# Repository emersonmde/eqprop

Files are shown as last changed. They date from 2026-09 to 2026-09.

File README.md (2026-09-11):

# Analog equilibrium propagation — XOR prototype B.1

A two-hidden-node analog resistive network for learning XOR through equilibrium propagation. The circuit settles physically; a classic 5 V Arduino Nano will measure equilibria and update sixteen programmable resistances. **The PCB is routed and checked; Nano firmware and physical validation are not yet implemented/completed.**

Start every new session with [project state and next steps](docs/project-state.md). It records what exists, what remains, and where to find the design, fabrication, programming and debugging instructions.

## Working files

- [Native KiCad project](cad/eqprop-xor/eqprop-xor.kicad_pro), including its child sheets and local libraries.
- [Design rationale and datasheets](docs/design.md), [component/pin tables](docs/kicad/00-overview.md), [preferred-parts BOM](docs/bom-pcbway.csv).
- [PCBWay fabrication and assembly](docs/fabrication.md).
- [Nano firmware contract](docs/firmware.md), [bench bring-up](docs/bring-up.md), [demo operation](docs/operation.md).
- [Engineering review](docs/ee-review.md), [validation evidence](docs/validation/).

## Simulation and release checks

From the repository root, using Python 3 and a virtual environment:

```sh
python3 -m venv .venv
source .venv/bin/activate
python -m pip install -r sim/requirements.txt
PYTHONPATH=sim python -m pytest sim/tests -q
PYTHONPATH=sim python -m eqprop.xor
python tools/generate_bom.py
python tools/export_manufacturing.py
```

Install ngspice for the SPICE tests; those tests skip when it is absent, so skipped tests do not constitute a complete release check. KiCad 9's `kicad-cli` is required for manufacturing export. The script discovers PATH or the standard macOS install; `--kicad-cli` can specify another executable. Generated fabrication files go in ignored `build/manufacturing/`. Save the exact approved release with the PCBWay order records when an order is placed.

The regression suite checks KCL, gradients, training, quantization, SPICE behavior and BOM consistency. These are retained because later hardware/firmware changes need them. Nominal DC models do not prove stability, noise, component spread or online finite-tap learning.

## Papers and Attribution

This project is a from-scratch implementation of techniques described in the following papers. No code was reused from any existing repository.

**Core algorithm:**
- Scellier & Bengio, ["Equilibrium Propagation: Bridging the Gap Between Energy-Based Models and Backpropagation"](https://arxiv.org/abs/1602.05179) (Frontiers in Computational Neuroscience, 2017) — the equilibrium propagation framework: free-phase settling, nudge-phase perturbation, and gradient extraction from energy differences.

**Analog hardware formulation:**
- Kendall et al., ["Training End-to-End Analog Neural Networks with Equilibrium Propagation"](https://arxiv.org/abs/2006.01981) (2020) — extends EqProp to nonlinear resistive networks. This project uses their conductance-space gradient formula (Theorem 1: `dC/dG = (dV_nudge² - dV_free²) / (2β)`), their proof that antiparallel diode pairs are valid EqProp nonlinear elements (Theorem 2), and their XOR demonstration architecture (Figure 3, Appendix D.2) as a starting point. The complementary-input encoding and digital-weight-update pattern also follow their approach.

**Symmetric nudging:**
- Laborieux et al., ["Scaling Equilibrium Propagation to Deep ConvNets by Drastically Reducing its Computational Cost"](https://arxiv.org/abs/2006.03824) (ICLR 2021) — the symmetric nudge variant (both +β and -β) used in the training loop to cancel gradient estimation bias.

**Referenced in the hardware design upgrade path:**
- Laborieux & Zenke, ["Holomorphic Equilibrium Propagation Computes Exact Gradients Through Finite Size Oscillations"](https://arxiv.org/abs/2209.00530) (NeurIPS 2022) — oscillating nudge + DFT-based gradient extraction for exact gradients without finite-β bias.

## License

Apache 2.0. See [LICENSE](LICENSE).

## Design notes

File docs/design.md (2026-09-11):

# Revision B.1 update

B.1 adds a locally routed learn/stop input on Nano A6 and operating labels; the analog design below remains unchanged. See [usability revision](usability-revision.md).

# EqProp XOR — revision B

Revision B.1 is the current prototype design. The native KiCad hierarchy, PCB and `bom-pcbway.csv` supersede the revision A construction notes retained in Git history. Revision A had functional errors that passing a routing DRC could not detect.

## Signal path

Sixteen MCP4251-104E/SL programmable resistances form a complementary-input, two-hidden-node, differential-output network. TLV9064 buffers generate V_LOW and V_HIGH and separate V_MID returns for the two diode activations and current sources. Two TMUX1133PWR devices select the complementary inputs. Four BAT42W diodes implement the hidden-node nonlinearities. U17 buffers H1, H2, YP and YN before the ADS1115; 100 ohm/1 nF filters isolate its switched-capacitor inputs from the buffers.

## Corrections and component decisions

* U4/U5 select pins are 11=A and 10=B; common analog pins are 14=X1 and 15=X2 (and complementary equivalents). The previous schematic interchanged these groups. TMUX1133 uses the verified compatible pin arrangement with much lower on-resistance than CD4053B. [TI TMUX1133](https://www.ti.com/lit/ds/symlink/tmux1133.pdf)
* U1/U2/U17 use TLV9064IDR and U15 uses TLV9062IDR. CMOS input bias and rail-to-rail operation suit the high-impedance analog network. Input offset, drift and reference errors still require calibration. The 1 uF reference capacitors filter divider inputs; large capacitors no longer directly load buffer outputs. [TI TLV906x](https://www.ti.com/lit/ds/symlink/tlv9064.pdf)
* Each programmable weight has a 2.49 kohm, 1% fixed series resistor. With a 5.5 V maximum rail difference and the resistor at its -1% corner, current is below 2.24 mA even without relying on pot resistance. MCP4251 terminal current is limited to 2.5 mA. The nominal 75 ohm wiper and tied W/B terminals are included in the revised model. Device resistance tolerance means taps must be calibrated if absolute conductance is important. [Microchip DS22060B](https://ww1.microchip.com/downloads/aemDocuments/documents/OTH/ProductDocuments/DataSheets/22060b.pdf)
* ADS1115 inputs now see buffered signals rather than directly loading the learning nodes. Readings still require settling after channel switching and changes to input/weight/DAC settings. [TI ADS1115](https://www.ti.com/lit/ds/symlink/ads1115.pdf)
* Precision dividers, the differential amplifier and pump resistor ratios use 0.1%, 25 ppm/K thin-film resistors. Other resistors use common thick-film parts. Precision MPNs specify lead-free TNPW e3, not the similarly named lead-bearing TNPW series. [Vishay TNPW e3](https://www.vishay.com/docs/28758/tnpw_e3.pdf)

## Balanced nudge sources

Each pump uses Rin=1M from DAC to the positive input, Rpos=1M from positive input to load, Rout=1M from amplifier output to load, Rref=10k from V_MID_PUMP to negative input, and Rfb=20k from output to negative input. All five are 0.1%.

The balance condition is `(Rfb/Rref)*Rin = Rpos + Rout`. Including current through both load-connected resistors gives:

`I_load = 2 uA/V * (V_DAC - V_MID_PUMP)`

The previous 10k/10k/10k/10k/1M arrangement was not balanced and substantially loaded the network in its purported free phase. These are equations for the actual five-resistor topology, not a generic four-resistor current-source formula. [TI AN-1515](https://www.ti.com/lit/an/snoa474a/snoa474a.pdf)

For the balanced circuit, `V_amp = 1.5*(V_DAC + V_load) - 2*V_MID_PUMP`. Firmware must enforce output compliance and the DAC's physical output range. A conservative initial operating region is V_DAC within +/-0.5 V of measured V_MID_PUMP, with node voltages near midrail. Calculate bounds from actual supply and load voltage; do not blindly clamp only to DAC codes. Maintain at least 0.15 V estimated output headroom as a bring-up guard, then characterize the real load-dependent swing.

## Classifier

U1C produces `PRED = V_MID_PUMP + YP_BUF - YN_BUF` using four 100k, 0.1% resistors. U18A compares this against a hysteretic threshold derived from a 4.99k/5.62k divider. U18B inverts its logic to drive the complementary indicator. This gives a nominal midpoint near +0.148 V differential at 5 V supply, appropriate for XOR targets 0 and +0.3 V. A zero-difference comparator was inappropriate for those targets.

The 10k input and 2M feedback resistors give approximately 31 mV DC hysteresis at 5 V **including the divider's Thevenin resistance**. The two nominal differential thresholds are approximately +0.132 V and +0.163 V. Values scale with board supply. C31 filters the divider; this also affects switching transients. LEDs use low-current parts with 2.2k classifier series resistors. [TI TLV3202](https://www.ti.com/lit/ds/symlink/tlv3202.pdf)

## Power and assembly

USB-C is a 5 V power input with separate CC pull-downs. F1 is **MF-NSMF025X-2, 1206**, followed by an LM66100DCKR ideal-diode IC and TPS22918 with 10 nF CT for controlled rise time. QOD is intentionally unconnected because the Nano can power the board through its +5V header. Reverse blocking prevents backfeeding the USB-C connector. The PTC protects against sustained faults; it is not an accurate active current limiter or overvoltage protector. The ideal diode avoids a Schottky forward drop, preserving supply margin. Its CE pin is tied to its output for reverse-current protection, with a local 1 uF input capacitor. The fuse, switches and traces still introduce load-dependent voltage drop: the net named +5V is a nominal rail, not a regulated precision 5.000 V supply. Reference voltages and classifier thresholds are ratiometric. [Bourns MF-NSMF](https://www.bourns.com/docs/product-datasheets/mf-nsmf.pdf), [TI LM66100](https://www.ti.com/lit/ds/symlink/lm66100.pdf), [TI TPS22918](https://www.ti.com/lit/ds/symlink/tps22918.pdf)

Use the classic **5 V Arduino Nano A000005**. Other Nano-family boards and unverified clones are not automatically interchangeable. Its module/header, slide switches, LEDs and mechanically anchored USB connector remain through-hole. Analog ICs, pots, signal diodes, resistors and capacitors use surface-mount packages. The BOM is suitable for requesting a PCBWay assembly quote; stock, substitutions, module handling and assembly cost have not been confirmed by PCBWay. Do not substitute op-amps, muxes, diode technology or precision resistor tolerances without repeating the circuit review.

## Layout

The board remains 106 x 88 mm, two copper layers. Four M3 clearance holes were added. Local IC bypassing, ground pours on both layers, and ground stitching provide short return paths. Routing uses 0.25 mm minimum tracks and 0.25 mm general clearance, with 0.6/0.3 mm vias. Only pad-to-pad clearance inside J1 uses the manufacturer land pattern's 0.15 mm spacing. Board copper-edge clearance remains 0.5 mm. Use 1 oz copper for the reviewed spacing. [PCBWay standard capabilities](https://www.pcbway.com/capabilities.html)

See `ee-review.md`, `bring-up.md`, the test reports and the current KiCad project before fabrication. DC simulations and clean ERC/DRC establish specific checks; they do not establish analog stability, ESD compliance, assembly yield or physical learning performance.

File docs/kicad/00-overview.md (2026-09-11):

# Current KiCad project

Revision B.1 uses eight functional sheets and a matching routed two-layer PCB. Open `cad/eqprop-xor/eqprop-xor.kicad_pro`. Project-local symbol and footprint libraries must remain with the project. See [design](../design.md), [review](../ee-review.md) and [bring-up](../bring-up.md).

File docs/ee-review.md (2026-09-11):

# EqProp XOR — revision B.1 engineering review

The revised **prototype** is routed and passes the automated electrical/design-rule checks. The original routed board was not functionally ready: the mux pin assignments and nudge-current circuit required correction. This revision is saved without a Git commit.

## B.1 usability update

See [usability revision](usability-revision.md). Adds SW3 on Nano A6 and R_BUTTON1, aligns the prediction LEDs, moves one LED resistor locally, adds operating labels and a back-side circuit guide, and records black mask / white silk / ENIG. The original analog topology and component values are unchanged.

## Changes resolved

| Area | Finding and resolution |
|---|---|
| Input selection | Corrected control/common pin interchange on U4/U5; changed to TMUX1133PWR with substantially lower switch resistance. |
| Nudge current | Rebalanced the five-resistor Howland topology to 2 uA/V. Verified both channels against SPICE using the actual component/pin manifest. |
| Analog loading | Replaced bipolar-input amplifiers with TLV906x; added four local measurement buffers and 100 ohm/1 nF ADC isolation filters. |
| Reference stability | Moved large reference capacitors to divider inputs, added local IC bypassing, and used 0.1% reference-divider resistors. |
| Weight protection | Changed all fixed series resistors to 2.49k, 1%; corrected the 257-position digital-pot/wiper model. |
| Output indicator | Added a buffered differential stage and hysteretic comparator around the actual XOR decision boundary. Selected low-current LEDs. |
| USB power | Added a 1206 PTC, LM66100 ideal-diode reverse blocking, TPS22918 controlled startup, and appropriate local capacitance. |
| Physical layout | Replaced DIP packages with SMD ICs/pots, arranged analog sections, routed both layers, stitched ground including previously isolated back-copper regions, added four mounting holes and test/operating labels. |
| Documentation / assembly | Rebuilt the native hierarchy, reconciled every assembly part with its footprint/MPN, updated simulation and firmware interface notes, and archived obsolete construction instructions. |

## Verified results

* KiCad DRC: **0 violations, 0 unrouted connections, 0 schematic/PCB mismatches**.
* KiCad ERC: **0 violations**, without blanket suppression of rule categories.
* Exported schematic netlist: **500 connected pins checked across 147 electrical symbols; 0 mismatches** against the intended manifest.
* Simulation suite: **47 passed**. The pump regression exercises 18 SPICE cases across both channels, DAC=2/2.5/3 V and load=2.2/2.5/2.8 V; current error stays below 1 nA in the finite-gain DC model.
* Analytical pump resistor-corner check: all 32 combinations of five 0.1% resistor extremes were evaluated over the same voltage sweep; worst modeled current error is approximately 2.91 nA.
* Nominal training plus final weight quantization preserves XOR classification at 4.4, 4.7 and 5.0 V in the model, using beta=1e-6 A/V. This is continuous training followed by quantization, not proof of a physical quantized-update training loop.

| Modeled supply | Quantized predictions: 00, 01, 10, 11 (V) |
|---|---|
| 4.4 V | 0.0522, 0.2544, 0.2658, 0.0638 |
| 4.7 V | 0.0492, 0.2480, 0.2616, 0.0632 |
| 5.0 V | 0.0465, 0.2497, 0.2603, 0.0603 |

The board is 106 x 88 mm with two copper layers, 151 footprints (131 populated components, 16 copper test points and four mounting holes), 347 vias including 151 ground vias. The increased via count includes deliberate ground stitching and the added SMD circuitry; this revision does not claim fewer vias than the original board.

## Files and manufacturing settings

Open `cad/eqprop-xor/eqprop-xor.kicad_pro`. Keep its local symbol/footprint libraries and `.kicad_dru` file together. Generate `build/manufacturing/` with `tools/export_manufacturing.py` for Gerbers, Excellon drill, top SMD positions, assembly drawing and schematic PDF. The position file contains 124 SMD parts; seven through-hole items need a separate assembly operation. Coordinates are the matching KiCad global origin in millimeters. Inspect the assembler's imported orientations and polarity marks before accepting its assembly preview.

Use 1.6 mm FR-4, two layers, 1 oz copper, solder mask on both sides, and the provided paste apertures. The reviewed rules use 0.25 mm routing clearance/trace minimum, 0.6/0.3 mm vias and 0.5 mm copper-edge clearance. J1 alone has a documented 0.15 mm internal pad-spacing rule matching its vendor footprint. [PCBWay capabilities](https://www.pcbway.com/capabilities.html)

`bom-pcbway.csv` has exact preferred MPNs; no PCBWay stock or substitution approval is implied. The Nano is the classic 5 V A000005 module. Keep switches, LEDs and the mechanically anchored connector as specified. Through-hole components should be installed after SMD reflow unless the assembler confirms another supported process.

## Interpretation of checks and remaining physical work

**Do not carry the old firmware constants into this board.** The pump transresistance is now 500 kohm, free-phase DAC voltage must track measured V_MID_PUMP, and all current commands need compliance limits. See [bring-up and firmware requirements](bring-up.md).

DC models do not prove amplifier stability, noise, leakage at temperature, startup sequencing, ADC settling, component spread, or learning on physical hardware. The per-branch mux resistance in the Python solver is an approximation; the full analog SPICE generator models shared mux outputs. Its amplifier model is a generic DC approximation, not a validated TLV906x vendor macro-model. The 0.15 V headroom in the bring-up notes is a conservative guard to characterize, not a guaranteed output-swing specification.

Before a larger batch, measure free-phase residual current, pump compliance and polarity, supply startup/backfeed, reference and measurement-buffer stability, conversion settling, and all four trained XOR patterns. PCBWay still needs to confirm part sourcing, module handling, assembly preview and DFM acceptance. No order was placed and no files were sent to PCBWay.

The project-local LM66100 symbol explicitly models the unused status pin as its datasheet-required grounded termination. Its passive pin type avoids a false ERC conflict between an open-drain output and the ground power flag; it must not be reused when ST is used as a logic output. [TI LM66100 pin table](https://www.ti.com/lit/ds/symlink/lm66100.pdf)

## Current handoff

See [project state](project-state.md) for fabrication, firmware and bench work. The pre-commit review fixed duplicate BOM counting, resistor metadata, stalled solver acceptance and schematic readability, and clarified startup/calibration. The later repository cleanup removed duplicate historical documents and added reproducible manufacturing export. Copper and preferred components are unchanged. The old schematic/PCB checks establish only the specific properties listed above; no physical demo performance is claimed.

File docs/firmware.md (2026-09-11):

# Classic Nano firmware contract — implementation pending

No Arduino sketch, compiled image or tested flashing command is supplied yet. Start with diagnostics; confirm the installed Nano and bootloader through the programming tool before selecting a target or upload settings. The native schematic and component manifest are authoritative for physical pin numbers.

## Arduino signal map

| Arduino pin | Board function |
|---|---|
| D0 / D1 | UART RX / TX; reserve for programming and serial diagnostics |
| D2 / D3 | MUX_A / MUX_B; input for manual switches, output for training override |
| D4, D5, D6, D7, D8 | CS_POT1 through CS_POT5 |
| D9 | CS_DAC |
| D10 | CS_POT6; keep configured as inactive-high output when SPI master is used |
| D11 / D12 / D13 | MOSI / MISO / SCK |
| A0 / A1 | X1 / X2 analog observation |
| A2 / A3 | CS_POT7 / CS_POT8 |
| A4 / A5 | I2C SDA / SCL |
| A6 | LEARN_BUTTON, active low, external pull-up; analog read only |
| A7 | Unconnected |

ADS1115 ADDR is grounded; channels AIN0..3 measure buffered H1, H2, YP, YN. Confirm protocol addresses, register masks and SPI timing from the manufacturer datasheets linked in design.md before implementing drivers. MCP4251 commands must preserve the ninth data bit for tap 256. Read back taps and verify device/channel-to-weight mapping from the manifest, not just chip enumeration.

## Implementation milestones

1. **Diagnostic firmware:** report identity/version over serial; exercise chip-selects and pot readback; configure ADC and read all channels; command both DAC channels using measured calibration. Check manual-input encoding. Keep CS high before enabling SPI and do not report valid predictions during initialization.
2. **Measurement engine:** implement the startup, active zero-current commands, compliance bounds, sequential DAC update handling, ADC scan and measured settling requirements in bring-up.md. No SPI writes during equilibrium sampling. Record raw ADC codes and calibrated voltages.
3. **Training engine:** port the mathematical convention from sim/eqprop/training.py. Weights are stored as resistance; gradients and updates use conductance. The reference uses free and symmetric nudged equilibria; maintain input and weight state across the complete phase group. Bound nudge commands, reject clipping/unsettled samples and accumulate sub-tap updates before quantizing.
4. **Control and persistence:** use the SW3 debounce/release rules in usability-revision.md. Stop only at phase boundaries, restore calibrated free phase and return switches to manual control. Preserve learned weights on stop. Add explicit save/restore with version/checksum and avoid writing nonvolatile memory on every update. Report mode, validity, errors and progress over serial.
5. **Acceptance:** test tap endpoints and channel map, startup/reset, held button, repeated presses, stop during learning, missing peripherals, power-cycle restore and all four XOR patterns. Compare raw measurements against simulation using actual calibrated tap values. Add firmware tests alongside the implemented code; do not claim completion from this contract.

Keep the first implementation small and observable. Define firmware source/build instructions when a toolchain is selected; no invented build layout or untested upload command is required in advance.

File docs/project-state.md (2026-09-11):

# Session handoff — B.1

Last updated: 2026-09-10. Read this before resuming fabrication, firmware, debugging or demonstrations.

## Current state

| Stage | Status |
|---|---|
| Electrical design and PCB | B.1 routed, 106 × 88 mm, two layers; reviewed SMD analog design with local libraries and custom rules. |
| Verification | 47 regression tests pass with ngspice available; KiCad ERC/DRC and schematic parity clean; 500 connected pins checked against manifest. Evidence under validation/. |
| Manufacturing | Preferred parts selected; 131 fitted parts (124 SMD, seven THT), 16 copper test points and four mounting holes. No PCBWay upload/order/payment is recorded. Sourcing, substitutions and DFM are unconfirmed. |
| Firmware | No Nano firmware source or verified flashing procedure exists yet. Python training is the reference algorithm, not MCU firmware. |
| Physical hardware | Not received or tested. No measured calibration, power budget, stability, settling or real learning results. |

The user selected black solder mask, white silkscreen and ENIG, with 1.6 mm FR-4 and 1 oz copper. Last discussed quantity was five PCBs with two assembled; reconfirm quantities and current pricing at checkout. The prior browser login/quote is not durable project state.

## Resume by stage

1. **Fabrication:** follow fabrication.md. Generate a fresh package locally, check its logs and hashes, review PCBWay's sourcing and placement preview, then obtain order approval. Do not upload an old chat artifact merely because its filename says B.1.
2. **Programming:** follow firmware.md and the native io.kicad_sch. Implement hardware diagnostics first, then calibrated sampling and phase control, then learning and persistence.
3. **Debugging:** follow bring-up.md. Save real observations in `docs/bench/` with board ID, supply, firmware commit, settings, instruments and pass/fail results. Start from power/reference tests before relying on classification.
4. **Demo:** follow operation.md only after startup validity, saved-weight restoration and all XOR patterns have been physically verified.

## Design constraints that must survive context resets

- Six clamped nodes: X1, its complement, X2, its complement, V_LOW and V_HIGH. Two diode nonlinear hidden nodes H1/H2; differential output YP−YN. Target 0 V for 00/11 and +0.3 V for 01/10.
- Sixteen weights use eight MCP4251-104E/SL chips, W tied to B, with 2.49 kohm fixed series resistors. Codes are 0..256 inclusive. Resistance/tap calibration is device dependent.
- TMUX1133 input selection, TLV906x references/measurement buffers, ADS1115 sampling, MCP4822 dual DAC and balanced Howland pumps are the current design. Old CD4053/LM324/MCP600x notes do not describe this board.
- Pump current is `2e-6 * (V_DAC - V_MID_PUMP)` A. Free phase uses calibrated active DAC outputs, not shutdown or a hardcoded 2.500 V. TP5 measures V_MID_PUMP; it is not automatically sampled by the MCU.
- The nominal model uses beta=1e-6 A/V. Firmware must enforce measured DAC/pump compliance and settling. Do not copy obsolete large-beta examples into hardware.
- ADC channels are buffered; the default ±2.048 V PGA setting clips midrail. See bring-up.md for range and sequencing.
- SW3 uses analog-only Nano A6, with an external 2.2 kohm pull-up. Prediction LEDs show class, not training/validity status. Runtime state must be reported over serial.
- Manual input switches are connected through 10 kohm resistors, allowing MCU override for training. Restore high-impedance control for manual operation.
- USB-C supplies nominal 5 V through PTC, reverse blocking and controlled rise time. Use classic 5 V Nano A000005; alternative Nano models/clones are not automatically compatible.

## Evidence limits

The corrected solver checks finite voltages and KCL residuals, retrying stalled solves. Gradient checks cover all four patterns. Training followed by final quantization passes modeled comparator thresholds at 4.4, 4.7 and 5.0 V, with separate training at each supply. This is not validation of online quantized training or supply-invariant stored weights. Diode parameters are nominal assumptions and op-amp models are generic DC approximations.

## Repository map and maintenance

Native CAD and intended component/pin manifest are under cad/eqprop-xor/. docs/design.md contains equations and datasheet links; docs/kicad/ contains convenient pin tables, secondary to the native design. tools/ contains reproducible BOM and manufacturing exports. sim/ and spice/ contain useful models and regressions. build/ is disposable generated output and is not versioned.

Revision A duplicate documents, stale schematic image, redundant BOM alias and duplicate check reports were removed during cleanup. Git retains previously committed history. Do not delete tests merely because they are not firmware: their purpose is detecting circuit/model regressions.

After each stage, update the status table and record exact order ID/release hashes, firmware commit, measurements or operating steps as applicable. Never mark a planned check as passed.

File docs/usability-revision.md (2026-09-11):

# Revision B.1: small demo-interface improvements

This supersedes B for fabrication. The board remains 106 x 88 mm, two layers, 1.6 mm FR-4 and 1 oz copper. Finish preference: black solder mask both sides, white silkscreen both sides, ENIG. The 3D render uses generic red LED models; the BOM still specifies green LEDs. Nano and slide-switch models are absent, so render imagery is not a complete mechanical assembly model.

## Changes

- Existing prediction LEDs now share an X coordinate beside the input switches. D_GRN2 indicates 0; D_GRN1 indicates 1. One series resistor moved locally to maintain courtyard clearance. Only the affected terminal routes were modified; the analog ICs and power entry stayed in place.
- INPUT X1 / INPUT X2, switch-state marks, PREDICTION, POWER and LEARN / STOP clarify the controls. Component references and debug net labels remain. Verify switch continuity against the printed states during first bring-up before applying automated input drive.
- Back-side guide shows complementary inputs, hidden nodes H1/H2, differential output YP/YN, bidirectional resistive coupling, the free/nudged comparison and XOR truth table. It is a functional guide, not a replacement for the full schematic.
- SW3 is a normally-open B3U-1000P momentary switch from LEARN_BUTTON to GND. Nano A6 (module pad 25) reads it. R_BUTTON1, 2.2k 1%, pulls the input to +5V. The resistor reuses the existing LED resistor MPN. Pressed current is approximately 2.3 mA at nominal 5 V; the unpressed input consumes no intentional DC current.
- A6 is analog-only on the classic Nano. This avoids UART sharing and changes to the existing SPI/I2C allocation. A separate MCU-driven status LED was omitted because no general-purpose digital output is free without sharing an existing function.

## Firmware contract — not implemented in this hardware revision

Read A6 with analogRead using the supply-referenced ADC setting. Use thresholds comfortably separated from midscale (for example below one-quarter full scale = pressed, above three-quarters = released); ignore intermediate samples. These thresholds are chosen margins for a rail-to-rail contact input, not precision voltage measurements. Debounce in software: require a stable state for 20 ms (engineering margin over the switch's specified 5 ms maximum bounce). Require release before accepting another press; a held button at boot must not repeatedly start training.

A press requests start/stop, processed only between completed free/nudged measurement pairs. On stop, return both DACs to calibrated free-phase commands before returning input control to the switches. Do not erase learned weights. Preserve programming/serial access. Report the mode and progress over serial; the prediction LEDs do not indicate training status. Save/restore weights and clear startup validity must be implemented in the eventual demo firmware. No complete MCU training firmware exists in this package.

Poll the button outside sensitive equilibrium-sampling windows. Test held-at-boot, contact bounce, repeated presses and stop during training. Confirm analog settling and classification with the button pressed/released as part of prototype validation.

## Assembly note

B3U-1000P is not washable. PCBWay must confirm a compatible no-clean assembly process or fit SW3 after wet cleaning. Do not approve a substitute without checking footprint, height, actuation and contact ratings. Counts per board: 124 SMD parts, 7 through-hole parts, 16 copper test points and 4 mounting holes (151 footprints total).

## Sources

- [Arduino classic Nano pinout](https://docs.arduino.cc/resources/pinouts/A000005-full-pinout.pdf): A6 is ADC6; no digital GPIO assignment.
- [Omron B3U datasheet](https://omronfs.omron.com/en_US/ecb/products/pdf/en-b3u.pdf): B3U-1000P top actuation, land pattern, normally-open contact, 5 ms maximum bounce, and non-washable construction.
- [Vishay CRCW datasheet](https://www.vishay.com/docs/20035/dcrcwe3.pdf): resistor series used for the pull-up, matching the existing 2.2k MPN.

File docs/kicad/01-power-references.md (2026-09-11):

# Revision B: power references

Use the native hierarchical schematic. Older wiring instructions do not apply to this revision. See [design](../design.md) and [bring-up](../bring-up.md).

| Reference | Value / MPN | Pin-to-net map |
|---|---|---|
| C8 | 1uF / C0805C105K4RACTU | 1=V_HIGH_RAW, 2=GND |
| C12 | 10uF / C0805C106K8PACTU | 1=+5V, 2=GND |
| C13 | 10uF / C0805C106K8PACTU | 1=+5V, 2=GND |
| U1 | TLV9064IDR / TLV9064IDR | 1=V_LOW, 2=V_LOW, 3=V_LOW_RAW, 4=+5V, 5=V_HIGH_RAW, 6=V_HIGH, 7=V_HIGH, 8=PRED, 9=PRED_MINUS, 10=PRED_PLUS, 11=GND, 12=V_MID_RAW, 13=PARK_U1, 14=PARK_U1 |
| R_CC2 | 5.1k / CRCW08055K10FKEA | 1=J1_CC2, 2=GND |
| C4 | 1uF / C0805C105K4RACTU | 1=V_MID_RAW, 2=GND |
| R5 | 8.2k / TNPW08058K20BEEA | 1=+5V, 2=V_HIGH_RAW |
| R1 | 10k / TNPW080510K0BEEA | 1=+5V, 2=V_MID_RAW |
| J1 | USB_C_Receptacle_USB2.0_14P / USB4085-GF-A | A1=GND, A4=VBUS, A5=J1_CC1, A9=VBUS, A12=GND, B1=GND, B4=VBUS, B5=J1_CC2, B9=VBUS, B12=GND, S1=GND |
| C3 | 100nF / C0805C104K5RACTU | 1=+5V, 2=GND |
| R4 | 8.2k / TNPW08058K20BEEA | 1=V_LOW_RAW, 2=GND |
| U2 | TLV9064IDR / TLV9064IDR | 1=V_MID_H1, 2=V_MID_H1, 3=V_MID_RAW, 4=+5V, 5=V_MID_RAW, 6=V_MID_H2, 7=V_MID_H2, 8=V_MID_PUMP, 9=V_MID_PUMP, 10=V_MID_RAW, 11=GND, 12=V_MID_RAW, 13=PARK_U2, 14=PARK_U2 |
| C2 | 100nF / C0805C104K5RACTU | 1=+5V, 2=GND |
| R_LED1 | 1k / CRCW08051K00FKEA | 1=+5V, 2=D_PWR1_A |
| R_CC1 | 5.1k / CRCW08055K10FKEA | 1=GND, 2=J1_CC1 |
| C9 | 1uF / C0805C105K4RACTU | 1=USB_PROTECTED, 2=GND |
| R2 | 10k / TNPW080510K0BEEA | 1=V_MID_RAW, 2=GND |
| C6 | 1uF / C0805C105K4RACTU | 1=V_LOW_RAW, 2=GND |
| R6 | 33k / TNPW080533K0BEEA | 1=V_HIGH_RAW, 2=GND |
| C1 | 1uF / C0805C105K4RACTU | 1=VBUS, 2=GND |
| R3 | 33k / TNPW080533K0BEEA | 1=+5V, 2=V_LOW_RAW |
| F1 | 250mA PTC / MF-NSMF025X-2 | 1=VBUS, 2=VBUS_FUSED |
| U19 | TPS22918DBVR / TPS22918DBVR | 1=USB_PROTECTED, 2=GND, 3=USB_PROTECTED, 4=SLEW_CT, 6=+5V |
| C29 | 10nF / C0805C103K5RACTU | 1=SLEW_CT, 2=GND |
| C30 | 10uF / C0805C106K8PACTU | 1=+5V, 2=GND |
| U20 | LM66100DCKR / LM66100DCKR | 1=VBUS_FUSED, 2=GND, 3=USB_PROTECTED, 5=GND, 6=USB_PROTECTED |
| C32 | 1uF / C0805C105K4RACTU | 1=VBUS_FUSED, 2=GND |

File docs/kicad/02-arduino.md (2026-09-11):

# Revision B.1: arduino

Use the native hierarchical schematic. Older wiring instructions do not apply to this revision. See [design](../design.md) and [bring-up](../bring-up.md).

| Reference | Value / MPN | Pin-to-net map |
|---|---|---|
| D_GRN1 | Green low-current 3mm / WP710A10LZGCK | 1=D_GRN1_K, 2=D_GRN1_A |
| R_SW1 | 10k / CRCW080510K0FKEA | 1=MUX_A, 2=SW1_B |
| R_SW2 | 10k / CRCW080510K0FKEA | 1=MUX_B, 2=SW2_B |
| SW1 | SW_SPDT / EG1271A | 1=+5V, 2=SW1_B, 3=GND |
| D_GRN2 | Green low-current 3mm / WP710A10LZGCK | 1=D_GRN2_K, 2=D_GRN2_A |
| U3 | Arduino_Nano_v3.x / A000005 | 4=GND, 5=MUX_A, 6=MUX_B, 7=CS_POT1, 8=CS_POT2, 9=CS_POT3, 10=CS_POT4, 11=CS_POT5, 12=CS_DAC, 13=CS_POT6, 14=SPI_MOSI, 15=SPI_MISO, 16=SPI_SCK, 19=X1, 20=X2, 21=CS_POT7, 22=CS_POT8, 23=I2C_SDA, 24=I2C_SCL, 25=LEARN_BUTTON, 27=+5V, 29=GND |
| SW2 | SW_SPDT / EG1271A | 1=+5V, 2=SW2_B, 3=GND |
| D_PWR1 | Green low-current 3mm / WP710A10LZGCK | 1=GND, 2=D_PWR1_A |

| SW3 | LEARN / STOP / B3U-1000P | 1=LEARN_BUTTON, 2=GND |
| R_BUTTON1 | 2.2k / CRCW08052K20FKEA | 1=+5V, 2=LEARN_BUTTON |

A6 is analog-only. See [button firmware contract](../usability-revision.md).

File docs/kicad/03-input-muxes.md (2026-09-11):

# Revision B: input muxes

Use the native hierarchical schematic. Older wiring instructions do not apply to this revision. See [design](../design.md) and [bring-up](../bring-up.md).

| Reference | Value / MPN | Pin-to-net map |
|---|---|---|
| U5 | TMUX1133PWR / TMUX1133PWR | 1=V_LOW, 2=V_HIGH, 3=GND, 4=GND, 5=GND, 6=GND, 7=GND, 8=GND, 9=GND, 10=MUX_B, 11=MUX_A, 12=V_HIGH, 13=V_LOW, 14=X1_COMP, 15=X2_COMP, 16=+5V |
| C19 | 100nF / C0805C104K5RACTU | 1=+5V, 2=GND |
| C18 | 100nF / C0805C104K5RACTU | 1=+5V, 2=GND |
| U4 | TMUX1133PWR / TMUX1133PWR | 1=V_HIGH, 2=V_LOW, 3=GND, 4=GND, 5=GND, 6=GND, 7=GND, 8=GND, 9=GND, 10=MUX_B, 11=MUX_A, 12=V_LOW, 13=V_HIGH, 14=X1, 15=X2, 16=+5V |

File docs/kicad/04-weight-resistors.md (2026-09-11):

# Revision B: weight resistors

Use the native hierarchical schematic. Older wiring instructions do not apply to this revision. See [design](../design.md) and [bring-up](../bring-up.md).

| Reference | Value / MPN | Pin-to-net map |
|---|---|---|
| R_W5 | 2.49k / CRCW08052K49FKEA | 1=U8_P0A, 2=X2 |
| R_W4 | 2.49k / CRCW08052K49FKEA | 1=X1_COMP, 2=U7_P1A |
| R_W3 | 2.49k / CRCW08052K49FKEA | 1=U7_P0A, 2=X1_COMP |
| R_W9 | 2.49k / CRCW08052K49FKEA | 1=U10_P0A, 2=V_LOW |
| U6 | MCP4251-104E/SL / MCP4251-104E/SL | 1=CS_POT1, 2=SPI_SCK, 3=SPI_MOSI, 4=GND, 5=H2, 6=H2, 7=U6_P1A, 8=U6_P0A, 9=H1, 10=H1, 11=+5V, 12=+5V, 13=SPI_MISO, 14=+5V |
| C22 | 100nF / C0805C104K5RACTU | 1=+5V, 2=GND |
| U10 | MCP4251-104E/SL / MCP4251-104E/SL | 1=CS_POT5, 2=SPI_SCK, 3=SPI_MOSI, 4=GND, 5=H2, 6=H2, 7=U10_P1A, 8=U10_P0A, 9=H1, 10=H1, 11=+5V, 12=+5V, 13=SPI_MISO, 14=+5V |
| R_W14 | 2.49k / CRCW08052K49FKEA | 1=H1, 2=U12_P1A |
| R_W7 | 2.49k / CRCW08052K49FKEA | 1=U9_P0A, 2=X2_COMP |
| U8 | MCP4251-104E/SL / MCP4251-104E/SL | 1=CS_POT3, 2=SPI_SCK, 3=SPI_MOSI, 4=GND, 5=H2, 6=H2, 7=U8_P1A, 8=U8_P0A, 9=H1, 10=H1, 11=+5V, 12=+5V, 13=SPI_MISO, 14=+5V |
| R14 | 10k / CRCW080510K0FKEA | 1=+5V, 2=CS_POT8 |
| U13 | MCP4251-104E/SL / MCP4251-104E/SL | 1=CS_POT8, 2=SPI_SCK, 3=SPI_MOSI, 4=GND, 5=YN, 6=YN, 7=U13_P1A, 8=U13_P0A, 9=YP, 10=YP, 11=+5V, 12=+5V, 13=SPI_MISO, 14=+5V |
| C21 | 100nF / C0805C104K5RACTU | 1=+5V, 2=GND |
| U12 | MCP4251-104E/SL / MCP4251-104E/SL | 1=CS_POT7, 2=SPI_SCK, 3=SPI_MOSI, 4=GND, 5=YN, 6=YN, 7=U12_P1A, 8=U12_P0A, 9=YP, 10=YP, 11=+5V, 12=+5V, 13=SPI_MISO, 14=+5V |
| R_W6 | 2.49k / CRCW08052K49FKEA | 1=X2, 2=U8_P1A |
| R11 | 10k / CRCW080510K0FKEA | 1=+5V, 2=CS_POT5 |
| R_W10 | 2.49k / CRCW08052K49FKEA | 1=V_LOW, 2=U10_P1A |
| C23 | 100nF / C0805C104K5RACTU | 1=+5V, 2=GND |
| U11 | MCP4251-104E/SL / MCP4251-104E/SL | 1=CS_POT6, 2=SPI_SCK, 3=SPI_MOSI, 4=GND, 5=H2, 6=H2, 7=U11_P1A, 8=U11_P0A, 9=H1, 10=H1, 11=+5V, 12=+5V, 13=SPI_MISO, 14=+5V |
| R12 | 10k / CRCW080510K0FKEA | 1=+5V, 2=CS_POT6 |
| R7 | 10k / CRCW080510K0FKEA | 1=+5V, 2=CS_POT1 |
| C25 | 100nF / C0805C104K5RACTU | 1=+5V, 2=GND |
| C20 | 100nF / C0805C104K5RACTU | 1=+5V, 2=GND |
| R_W13 | 2.49k / CRCW08052K49FKEA | 1=U12_P0A, 2=H1 |
| R13 | 10k / CRCW080510K0FKEA | 1=+5V, 2=CS_POT7 |
| C26 | 100nF / C0805C104K5RACTU | 1=+5V, 2=GND |
| U9 | MCP4251-104E/SL / MCP4251-104E/SL | 1=CS_POT4, 2=SPI_SCK, 3=SPI_MOSI, 4=GND, 5=H2, 6=H2, 7=U9_P1A, 8=U9_P0A, 9=H1, 10=H1, 11=+5V, 12=+5V, 13=SPI_MISO, 14=+5V |
| R8 | 10k / CRCW080510K0FKEA | 1=+5V, 2=CS_POT2 |
| R9 | 10k / CRCW080510K0FKEA | 1=+5V, 2=CS_POT3 |
| R_W12 | 2.49k / CRCW08052K49FKEA | 1=V_HIGH, 2=U11_P1A |
| R_W8 | 2.49k / CRCW08052K49FKEA | 1=X2_COMP, 2=U9_P1A |
| U7 | MCP4251-104E/SL / MCP4251-104E/SL | 1=CS_POT2, 2=SPI_SCK, 3=SPI_MOSI, 4=GND, 5=H2, 6=H2, 7=U7_P1A, 8=U7_P0A, 9=H1, 10=H1, 11=+5V, 12=+5V, 13=SPI_MISO, 14=+5V |
| R_W2 | 2.49k / CRCW08052K49FKEA | 1=X1, 2=U6_P1A |
| R10 | 10k / CRCW080510K0FKEA | 1=+5V, 2=CS_POT4 |
| R_W16 | 2.49k / CRCW08052K49FKEA | 1=H2, 2=U13_P1A |
| R_W1 | 2.49k / CRCW08052K49FKEA | 1=U6_P0A, 2=X1 |
| C24 | 100nF / C0805C104K5RACTU | 1=+5V, 2=GND |
| R_W15 | 2.49k / CRCW08052K49FKEA | 1=U13_P0A, 2=H2 |
| R_W11 | 2.49k / CRCW08052K49FKEA | 1=U11_P0A, 2=V_HIGH |

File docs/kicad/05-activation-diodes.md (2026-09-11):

# Revision B: activation diodes

Use the native hierarchical schematic. Older wiring instructions do not apply to this revision. See [design](../design.md) and [bring-up](../bring-up.md).

| Reference | Value / MPN | Pin-to-net map |
|---|---|---|
| R17 | 0 / CRCW08050000Z0EA | 1=H1, 2=D2_K |
| D2 | BAT42W-G3-08 / BAT42W-G3-08 | 1=D2_K, 2=V_MID_H1 |
| R18 | 0 / CRCW08050000Z0EA | 1=H2, 2=D4_K |
| R19 | 0 / CRCW08050000Z0EA | 1=D3_K, 2=V_MID_H2 |
| R16 | 0 / CRCW08050000Z0EA | 1=D1_K, 2=V_MID_H1 |
| D3 | BAT42W-G3-08 / BAT42W-G3-08 | 1=D3_K, 2=H2 |
| D4 | BAT42W-G3-08 / BAT42W-G3-08 | 1=D4_K, 2=V_MID_H2 |
| D1 | BAT42W-G3-08 / BAT42W-G3-08 | 1=D1_K, 2=H1 |

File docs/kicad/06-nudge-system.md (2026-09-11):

# Revision B: nudge system

Use the native hierarchical schematic. Older wiring instructions do not apply to this revision. See [design](../design.md) and [bring-up](../bring-up.md).

| Reference | Value / MPN | Pin-to-net map |
|---|---|---|
| R_H1 | 1M / TNPW08051M00BEEA | 1=DAC_OUTA, 2=U15A_P |
| R_H6 | 10k / TNPW080510K0BEEA | 1=V_MID_PUMP, 2=U15B_N |
| R_H5 | 1M / TNPW08051M00BEEA | 1=DAC_OUTB, 2=U15B_P |
| R15 | 10k / CRCW080510K0FKEA | 1=+5V, 2=CS_DAC |
| R_H3 | 20k / TNPW080520K0BEEA | 1=R_H3_1, 2=U15A_N |
| U15 | TLV9062IDR / TLV9062IDR | 1=R_H3_1, 2=U15A_N, 3=U15A_P, 4=GND, 5=U15B_P, 6=U15B_N, 7=R_H7_1, 8=+5V |
| R_H4 | 1M / TNPW08051M00BEEA | 1=R_H3_1, 2=YP |
| C15 | 100nF / C0805C104K5RACTU | 1=+5V, 2=GND |
| C14 | 100nF / C0805C104K5RACTU | 1=+5V, 2=GND |
| R_H2 | 10k / TNPW080510K0BEEA | 1=V_MID_PUMP, 2=U15A_N |
| R_H7 | 20k / TNPW080520K0BEEA | 1=R_H7_1, 2=U15B_N |
| U14 | MCP4822-E/SN / MCP4822-E/SN | 1=+5V, 2=CS_DAC, 3=SPI_SCK, 4=SPI_MOSI, 5=GND, 6=DAC_OUTB, 7=GND, 8=DAC_OUTA |
| R_SET_B1 | 1M / TNPW08051M00BEEA | 1=YN, 2=U15B_P |
| R_SET_A1 | 1M / TNPW08051M00BEEA | 1=U15A_P, 2=YP |
| R_H8 | 1M / TNPW08051M00BEEA | 1=R_H7_1, 2=YN |
| C16 | 100nF / C0805C104K5RACTU | 1=+5V, 2=GND |

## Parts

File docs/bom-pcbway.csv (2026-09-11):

References | Quantity | Value | Footprint | Manufacturer part number | Tolerance / rating | Datasheet | Assembly notes
C1 | 1 | 1uF | Capacitor_SMD:C_0805_2012Metric | C0805C105K4RACTU | 10%, X7R, 16V | https://search.kemet.com/component-documentation/download/specsheet/C0805C105K4RACTU | Top-side SMD
C10 | 1 | 1nF | Capacitor_SMD:C_0805_2012Metric | C0805C102J5GACTU | 5%, C0G, 50V | https://search.kemet.com/component-documentation/download/specsheet/C0805C102J5GACTU | Top-side SMD
C11 | 1 | 1nF | Capacitor_SMD:C_0805_2012Metric | C0805C102J5GACTU | 5%, C0G, 50V | https://search.kemet.com/component-documentation/download/specsheet/C0805C102J5GACTU | Top-side SMD
C12 | 1 | 10uF | Capacitor_SMD:C_0805_2012Metric | C0805C106K8PACTU | 10%, X5R, 10V | https://search.kemet.com/component-documentation/download/specsheet/C0805C106K8PACTU | Top-side SMD
C13 | 1 | 10uF | Capacitor_SMD:C_0805_2012Metric | C0805C106K8PACTU | 10%, X5R, 10V | https://search.kemet.com/component-documentation/download/specsheet/C0805C106K8PACTU | Top-side SMD
C14 | 1 | 100nF | Capacitor_SMD:C_0805_2012Metric | C0805C104K5RACTU | 10%, X7R, 50V | https://search.kemet.com/component-documentation/download/specsheet/C0805C104K5RACTU | Top-side SMD
C15 | 1 | 100nF | Capacitor_SMD:C_0805_2012Metric | C0805C104K5RACTU | 10%, X7R, 50V | https://search.kemet.com/component-documentation/download/specsheet/C0805C104K5RACTU | Top-side SMD
C16 | 1 | 100nF | Capacitor_SMD:C_0805_2012Metric | C0805C104K5RACTU | 10%, X7R, 50V | https://search.kemet.com/component-documentation/download/specsheet/C0805C104K5RACTU | Top-side SMD
C17 | 1 | 100nF | Capacitor_SMD:C_0805_2012Metric | C0805C104K5RACTU | 10%, X7R, 50V | https://search.kemet.com/component-documentation/download/specsheet/C0805C104K5RACTU | Top-side SMD
C18 | 1 | 100nF | Capacitor_SMD:C_0805_2012Metric | C0805C104K5RACTU | 10%, X7R, 50V | https://search.kemet.com/component-documentation/download/specsheet/C0805C104K5RACTU | Top-side SMD
C19 | 1 | 100nF | Capacitor_SMD:C_0805_2012Metric | C0805C104K5RACTU | 10%, X7R, 50V | https://search.kemet.com/component-documentation/download/specsheet/C0805C104K5RACTU | Top-side SMD
C2 | 1 | 100nF | Capacitor_SMD:C_0805_2012Metric | C0805C104K5RACTU | 10%, X7R, 50V | https://search.kemet.com/component-documentation/download/specsheet/C0805C104K5RACTU | Top-side SMD
C20 | 1 | 100nF | Capacitor_SMD:C_0805_2012Metric | C0805C104K5RACTU | 10%, X7R, 50V | https://search.kemet.com/component-documentation/download/specsheet/C0805C104K5RACTU | Top-side SMD
C21 | 1 | 100nF | Capacitor_SMD:C_0805_2012Metric | C0805C104K5RACTU | 10%, X7R, 50V | https://search.kemet.com/component-documentation/download/specsheet/C0805C104K5RACTU | Top-side SMD
C22 | 1 | 100nF | Capacitor_SMD:C_0805_2012Metric | C0805C104K5RACTU | 10%, X7R, 50V | https://search.kemet.com/component-documentation/download/specsheet/C0805C104K5RACTU | Top-side SMD
C23 | 1 | 100nF | Capacitor_SMD:C_0805_2012Metric | C0805C104K5RACTU | 10%, X7R, 50V | https://search.kemet.com/component-documentation/download/specsheet/C0805C104K5RACTU | Top-side SMD
C24 | 1 | 100nF | Capacitor_SMD:C_0805_2012Metric | C0805C104K5RACTU | 10%, X7R, 50V | https://search.kemet.com/component-documentation/download/specsheet/C0805C104K5RACTU | Top-side SMD
C25 | 1 | 100nF | Capacitor_SMD:C_0805_2012Metric | C0805C104K5RACTU | 10%, X7R, 50V | https://search.kemet.com/component-documentation/download/specsheet/C0805C104K5RACTU | Top-side SMD
C26 | 1 | 100nF | Capacitor_SMD:C_0805_2012Metric | C0805C104K5RACTU | 10%, X7R, 50V | https://search.kemet.com/component-documentation/download/specsheet/C0805C104K5RACTU | Top-side SMD
C27 | 1 | 1nF | Capacitor_SMD:C_0805_2012Metric | C0805C102J5GACTU | 5%, C0G, 50V | https://search.kemet.com/component-documentation/download/specsheet/C0805C102J5GACTU | Top-side SMD
C28 | 1 | 1nF | Capacitor_SMD:C_0805_2012Metric | C0805C102J5GACTU | 5%, C0G, 50V | https://search.kemet.com/component-documentation/download/specsheet/C0805C102J5GACTU | Top-side SMD
C29 | 1 | 10nF | Capacitor_SMD:C_0805_2012Metric | C0805C103K5RACTU | 10%, X7R, 50V | https://search.kemet.com/component-documentation/download/specsheet/C0805C103K5RACTU | Top-side SMD
C3 | 1 | 100nF | Capacitor_SMD:C_0805_2012Metric | C0805C104K5RACTU | 10%, X7R, 50V | https://search.kemet.com/component-documentation/download/specsheet/C0805C104K5RACTU | Top-side SMD
C30 | 1 | 10uF | Capacitor_SMD:C_0805_2012Metric | C0805C106K8PACTU | 10%, X5R, 10V | https://search.kemet.com/component-documentation/download/specsheet/C0805C106K8PACTU | Top-side SMD
C31 | 1 | 100nF | Capacitor_SMD:C_0805_2012Metric | C0805C104K5RACTU | 10%, X7R, 50V | https://search.kemet.com/component-documentation/download/specsheet/C0805C104K5RACTU | Top-side SMD
C32 | 1 | 1uF | Capacitor_SMD:C_0805_2012Metric | C0805C105K4RACTU | 10%, X7R, 16V | https://search.kemet.com/component-documentation/download/specsheet/C0805C105K4RACTU | Top-side SMD
C4 | 1 | 1uF | Capacitor_SMD:C_0805_2012Metric | C0805C105K4RACTU | 10%, X7R, 16V | https://search.kemet.com/component-documentation/download/specsheet/C0805C105K4RACTU | Top-side SMD
C5 | 1 | 100nF | Capacitor_SMD:C_0805_2012Metric | C0805C104K5RACTU | 10%, X7R, 50V | https://search.kemet.com/component-documentation/download/specsheet/C0805C104K5RACTU | Top-side SMD
C6 | 1 | 1uF | Capacitor_SMD:C_0805_2012Metric | C0805C105K4RACTU | 10%, X7R, 16V | https://search.kemet.com/component-documentation/download/specsheet/C0805C105K4RACTU | Top-side SMD
C7 | 1 | 100nF | Capacitor_SMD:C_0805_2012Metric | C0805C104K5RACTU | 10%, X7R, 50V | https://search.kemet.com/component-documentation/download/specsheet/C0805C104K5RACTU | Top-side SMD
C8 | 1 | 1uF | Capacitor_SMD:C_0805_2012Metric | C0805C105K4RACTU | 10%, X7R, 16V | https://search.kemet.com/component-documentation/download/specsheet/C0805C105K4RACTU | Top-side SMD
C9 | 1 | 1uF | Capacitor_SMD:C_0805_2012Metric | C0805C105K4RACTU | 10%, X7R, 16V | https://search.kemet.com/component-documentation/download/specsheet/C0805C105K4RACTU | Top-side SMD
D1 | 1 | BAT42W-G3-08 | Diode_SMD:D_SOD-123 | BAT42W-G3-08 |  | https://www.vishay.com/docs/86405/bat42w-g.pdf | Top-side SMD
D2 | 1 | BAT42W-G3-08 | Diode_SMD:D_SOD-123 | BAT42W-G3-08 |  | https://www.vishay.com/docs/86405/bat42w-g.pdf | Top-side SMD
D3 | 1 | BAT42W-G3-08 | Diode_SMD:D_SOD-123 | BAT42W-G3-08 |  | https://www.vishay.com/docs/86405/bat42w-g.pdf | Top-side SMD
D4 | 1 | BAT42W-G3-08 | Diode_SMD:D_SOD-123 | BAT42W-G3-08 |  | https://www.vishay.com/docs/86405/bat42w-g.pdf | Top-side SMD
D_GRN1 | 1 | Green low-current 3mm | LED_THT:LED_D3.0mm | WP710A10LZGCK |  | https://www.kingbrightusa.com/images/catalog/SPEC/WP710A10LZGCK.pdf | Through-hole assembly
D_GRN2 | 1 | Green low-current 3mm | LED_THT:LED_D3.0mm | WP710A10LZGCK |  | https://www.kingbrightusa.com/images/catalog/SPEC/WP710A10LZGCK.pdf | Through-hole assembly
D_PWR1 | 1 | Green low-current 3mm | LED_THT:LED_D3.0mm | WP710A10LZGCK |  | https://www.kingbrightusa.com/images/catalog/SPEC/WP710A10LZGCK.pdf | Through-hole assembly
F1 | 1 | 250mA PTC | Fuse:Fuse_1206_3216Metric | MF-NSMF025X-2 |  | https://www.bourns.com/docs/product-datasheets/mf-nsmf.pdf | Top-side SMD
J1 | 1 | USB_C_Receptacle_USB2.0_14P | EqProp:USB4085_Edge | USB4085-GF-A |  | https://gct.co/connector/usb4085 | Through-hole assembly
R1 | 1 | 10k | Resistor_SMD:R_0805_2012Metric | TNPW080510K0BEEA | 0.1%; 0.125 W minimum; 25 ppm/K | https://www.vishay.com/docs/28758/tnpw_e3.pdf | Top-side SMD
R10 | 1 | 10k | Resistor_SMD:R_0805_2012Metric | CRCW080510K0FKEA | 1%; 0.125 W; 100 ppm/K | https://www.vishay.com/docs/20035/dcrcwe3.pdf | Top-side SMD
R11 | 1 | 10k | Resistor_SMD:R_0805_2012Metric | CRCW080510K0FKEA | 1%; 0.125 W; 100 ppm/K | https://www.vishay.com/docs/20035/dcrcwe3.pdf | Top-side SMD
R12 | 1 | 10k | Resistor_SMD:R_0805_2012Metric | CRCW080510K0FKEA | 1%; 0.125 W; 100 ppm/K | https://www.vishay.com/docs/20035/dcrcwe3.pdf | Top-side SMD
R13 | 1 | 10k | Resistor_SMD:R_0805_2012Metric | CRCW080510K0FKEA | 1%; 0.125 W; 100 ppm/K | https://www.vishay.com/docs/20035/dcrcwe3.pdf | Top-side SMD
R14 | 1 | 10k | Resistor_SMD:R_0805_2012Metric | CRCW080510K0FKEA | 1%; 0.125 W; 100 ppm/K | https://www.vishay.com/docs/20035/dcrcwe3.pdf | Top-side SMD
R15 | 1 | 10k | Resistor_SMD:R_0805_2012Metric | CRCW080510K0FKEA | 1%; 0.125 W; 100 ppm/K | https://www.vishay.com/docs/20035/dcrcwe3.pdf | Top-side SMD
R16 | 1 | 0 | Resistor_SMD:R_0805_2012Metric | CRCW08050000Z0EA | Jumper; 0 ohm jumper; see manufacturer current rating | https://www.vishay.com/docs/20035/dcrcwe3.pdf | Top-side SMD
R17 | 1 | 0 | Resistor_SMD:R_0805_2012Metric | CRCW08050000Z0EA | Jumper; 0 ohm jumper; see manufacturer current rating | https://www.vishay.com/docs/20035/dcrcwe3.pdf | Top-side SMD
R18 | 1 | 0 | Resistor_SMD:R_0805_2012Metric | CRCW08050000Z0EA | Jumper; 0 ohm jumper; see manufacturer current rating | https://www.vishay.com/docs/20035/dcrcwe3.pdf | Top-side SMD
R19 | 1 | 0 | Resistor_SMD:R_0805_2012Metric | CRCW08050000Z0EA | Jumper; 0 ohm jumper; see manufacturer current rating | https://www.vishay.com/docs/20035/dcrcwe3.pdf | Top-side SMD
R2 | 1 | 10k | Resistor_SMD:R_0805_2012Metric | TNPW080510K0BEEA | 0.1%; 0.125 W minimum; 25 ppm/K | https://www.vishay.com/docs/28758/tnpw_e3.pdf | Top-side SMD
R20 | 1 | 4.7k | Resistor_SMD:R_0805_2012Metric | CRCW08054K70FKEA | 1%; 0.125 W; 100 ppm/K | https://www.vishay.com/docs/20035/dcrcwe3.pdf | Top-side SMD
R21 | 1 | 4.7k | Resistor_SMD:R_0805_2012Metric | CRCW08054K70FKEA | 1%; 0.125 W; 100 ppm/K | https://www.vishay.com/docs/20035/dcrcwe3.pdf | Top-side SMD
R3 | 1 | 33k | Resistor_SMD:R_0805_2012Metric | TNPW080533K0BEEA | 0.1%; 0.125 W minimum; 25 ppm/K | https://www.vishay.com/docs/28758/tnpw_e3.pdf | Top-side SMD
R4 | 1 | 8.2k | Resistor_SMD:R_0805_2012Metric | TNPW08058K20BEEA | 0.1%; 0.125 W minimum; 25 ppm/K | https://www.vishay.com/docs/28758/tnpw_e3.pdf | Top-side SMD
R5 | 1 | 8.2k | Resistor_SMD:R_0805_2012Metric | TNPW08058K20BEEA | 0.1%; 0.125 W minimum; 25 ppm/K | https://www.vishay.com/docs/28758/tnpw_e3.pdf | Top-side SMD
R6 | 1 | 33k | Resistor_SMD:R_0805_2012Metric | TNPW080533K0BEEA | 0.1%; 0.125 W minimum; 25 ppm/K | https://www.vishay.com/docs/28758/tnpw_e3.pdf | Top-side SMD
R7 | 1 | 10k | Resistor_SMD:R_0805_2012Metric | CRCW080510K0FKEA | 1%; 0.125 W; 100 ppm/K | https://www.vishay.com/docs/20035/dcrcwe3.pdf | Top-side SMD
R8 | 1 | 10k | Resistor_SMD:R_0805_2012Metric | CRCW080510K0FKEA | 1%; 0.125 W; 100 ppm/K | https://www.vishay.com/docs/20035/dcrcwe3.pdf | Top-side SMD
R9 | 1 | 10k | Resistor_SMD:R_0805_2012Metric | CRCW080510K0FKEA | 1%; 0.125 W; 100 ppm/K | https://www.vishay.com/docs/20035/dcrcwe3.pdf | Top-side SMD
R_ADC1 | 1 | 100 | Resistor_SMD:R_0805_2012Metric | CRCW0805100RFKEA | 1%; 0.125 W; 100 ppm/K | https://www.vishay.com/docs/20035/dcrcwe3.pdf | Top-side SMD
R_ADC2 | 1 | 100 | Resistor_SMD:R_0805_2012Metric | CRCW0805100RFKEA | 1%; 0.125 W; 100 ppm/K | https://www.vishay.com/docs/20035/dcrcwe3.pdf | Top-side SMD
R_ADC3 | 1 | 100 | Resistor_SMD:R_0805_2012Metric | CRCW0805100RFKEA | 1%; 0.125 W; 100 ppm/K | https://www.vishay.com/docs/20035/dcrcwe3.pdf | Top-side SMD
R_ADC4 | 1 | 100 | Resistor_SMD:R_0805_2012Metric | CRCW0805100RFKEA | 1%; 0.125 W; 100 ppm/K | https://www.vishay.com/docs/20035/dcrcwe3.pdf | Top-side SMD
R_BUTTON1 | 1 | 2.2k | Resistor_SMD:R_0805_2012Metric | CRCW08052K20FKEA | 1%; 0.125 W; 100 ppm/K | https://www.vishay.com/docs/20035/dcrcwe3.pdf | Top SMD
R_CC1 | 1 | 5.1k | Resistor_SMD:R_0805_2012Metric | CRCW08055K10FKEA | 1%; 0.125 W; 100 ppm/K | https://www.vishay.com/docs/20035/dcrcwe3.pdf | Top-side SMD
R_CC2 | 1 | 5.1k | Resistor_SMD:R_0805_2012Metric | CRCW08055K10FKEA | 1%; 0.125 W; 100 ppm/K | https://www.vishay.com/docs/20035/dcrcwe3.pdf | Top-side SMD
R_D1 | 1 | 100k | Resistor_SMD:R_0805_2012Metric | TNPW0805100KBEEA | 0.1%; 0.125 W minimum; 25 ppm/K | https://www.vishay.com/docs/28758/tnpw_e3.pdf | Top-side SMD
R_D2 | 1 | 100k | Resistor_SMD:R_0805_2012Metric | TNPW0805100KBEEA | 0.1%; 0.125 W minimum; 25 ppm/K | https://www.vishay.com/docs/28758/tnpw_e3.pdf | Top-side SMD
R_D3 | 1 | 100k | Resistor_SMD:R_0805_2012Metric | TNPW0805100KBEEA | 0.1%; 0.125 W minimum; 25 ppm/K | https://www.vishay.com/docs/28758/tnpw_e3.pdf | Top-side SMD
R_D4 | 1 | 100k | Resistor_SMD:R_0805_2012Metric | TNPW0805100KBEEA | 0.1%; 0.125 W minimum; 25 ppm/K | https://www.vishay.com/docs/28758/tnpw_e3.pdf | Top-side SMD
R_H1 | 1 | 1M | Resistor_SMD:R_0805_2012Metric | TNPW08051M00BEEA | 0.1%; 0.125 W minimum; 25 ppm/K | https://www.vishay.com/docs/28758/tnpw_e3.pdf | Top-side SMD
R_H2 | 1 | 10k | Resistor_SMD:R_0805_2012Metric | TNPW080510K0BEEA | 0.1%; 0.125 W minimum; 25 ppm/K | https://www.vishay.com/docs/28758/tnpw_e3.pdf | Top-side SMD
R_H3 | 1 | 20k | Resistor_SMD:R_0805_2012Metric | TNPW080520K0BEEA | 0.1%; 0.125 W minimum; 25 ppm/K | https://www.vishay.com/docs/28758/tnpw_e3.pdf | Top-side SMD
R_H4 | 1 | 1M | Resistor_SMD:R_0805_2012Metric | TNPW08051M00BEEA | 0.1%; 0.125 W minimum; 25 ppm/K | https://www.vishay.com/docs/28758/tnpw_e3.pdf | Top-side SMD
R_H5 | 1 | 1M | Resistor_SMD:R_0805_2012Metric | TNPW08051M00BEEA | 0.1%; 0.125 W minimum; 25 ppm/K | https://www.vishay.com/docs/28758/tnpw_e3.pdf | Top-side SMD
R_H6 | 1 | 10k | Resistor_SMD:R_0805_2012Metric | TNPW080510K0BEEA | 0.1%; 0.125 W minimum; 25 ppm/K | https://www.vishay.com/docs/28758/tnpw_e3.pdf | Top-side SMD
R_H7 | 1 | 20k | Resistor_SMD:R_0805_2012Metric | TNPW080520K0BEEA | 0.1%; 0.125 W minimum; 25 ppm/K | https://www.vishay.com/docs/28758/tnpw_e3.pdf | Top-side SMD
R_H8 | 1 | 1M | Resistor_SMD:R_0805_2012Metric | TNPW08051M00BEEA | 0.1%; 0.125 W minimum; 25 ppm/K | https://www.vishay.com/docs/28758/tnpw_e3.pdf | Top-side SMD
R_HYS1 | 1 | 10k | Resistor_SMD:R_0805_2012Metric | CRCW080510K0FKEA | 1%; 0.125 W; 100 ppm/K | https://www.vishay.com/docs/20035/dcrcwe3.pdf | Top-side SMD
R_HYS2 | 1 | 2M | Resistor_SMD:R_0805_2012Metric | CRCW08052M00FKEA | 1%; 0.125 W; 100 ppm/K | https://www.vishay.com/docs/20035/dcrcwe3.pdf | Top-side SMD
R_LED1 | 1 | 1k | Resistor_SMD:R_0805_2012Metric | CRCW08051K00FKEA | 1%; 0.125 W; 100 ppm/K | https://www.vishay.com/docs/20035/dcrcwe3.pdf | Top-side SMD
R_LED_G1 | 1 | 2.2k | Resistor_SMD:R_0805_2012Metric | CRCW08052K20FKEA | 1%; 0.125 W; 100 ppm/K | https://www.vishay.com/docs/20035/dcrcwe3.pdf | Top-side SMD
R_LED_R1 | 1 | 2.2k | Resistor_SMD:R_0805_2012Metric | CRCW08052K20FKEA | 1%; 0.125 W; 100 ppm/K | https://www.vishay.com/docs/20035/dcrcwe3.pdf | Top-side SMD
R_SET_A1 | 1 | 1M | Resistor_SMD:R_0805_2012Metric | TNPW08051M00BEEA | 0.1%; 0.125 W minimum; 25 ppm/K | https://www.vishay.com/docs/28758/tnpw_e3.pdf | Top-side SMD
R_SET_B1 | 1 | 1M | Resistor_SMD:R_0805_2012Metric | TNPW08051M00BEEA | 0.1%; 0.125 W minimum; 25 ppm/K | https://www.vishay.com/docs/28758/tnpw_e3.pdf | Top-side SMD
R_SW1 | 1 | 10k | Resistor_SMD:R_0805_2012Metric | CRCW080510K0FKEA | 1%; 0.125 W; 100 ppm/K | https://www.vishay.com/docs/20035/dcrcwe3.pdf | Top-side SMD
R_SW2 | 1 | 10k | Resistor_SMD:R_0805_2012Metric | CRCW080510K0FKEA | 1%; 0.125 W; 100 ppm/K | https://www.vishay.com/docs/20035/dcrcwe3.pdf | Top-side SMD
R_TH1 | 1 | 4.99k | Resistor_SMD:R_0805_2012Metric | TNPW08054K99BEEA | 0.1%; 0.125 W minimum; 25 ppm/K | https://www.vishay.com/docs/28758/tnpw_e3.pdf | Top-side SMD
R_TH2 | 1 | 5.62k | Resistor_SMD:R_0805_2012Metric | TNPW08055K62BEEA | 0.1%; 0.125 W minimum; 25 ppm/K | https://www.vishay.com/docs/28758/tnpw_e3.pdf | Top-side SMD
R_W1 | 1 | 2.49k | Resistor_SMD:R_0805_2012Metric | CRCW08052K49FKEA | 1%; 0.125 W; 100 ppm/K | https://www.vishay.com/docs/20035/dcrcwe3.pdf | Top-side SMD
R_W10 | 1 | 2.49k | Resistor_SMD:R_0805_2012Metric | CRCW08052K49FKEA | 1%; 0.125 W; 100 ppm/K | https://www.vishay.com/docs/20035/dcrcwe3.pdf | Top-side SMD
R_W11 | 1 | 2.49k | Resistor_SMD:R_0805_2012Metric | CRCW08052K49FKEA | 1%; 0.125 W; 100 ppm/K | https://www.vishay.com/docs/20035/dcrcwe3.pdf | Top-side SMD
R_W12 | 1 | 2.49k | Resistor_SMD:R_0805_2012Metric | CRCW08052K49FKEA | 1%; 0.125 W; 100 ppm/K | https://www.vishay.com/docs/20035/dcrcwe3.pdf | Top-side SMD
R_W13 | 1 | 2.49k | Resistor_SMD:R_0805_2012Metric | CRCW08052K49FKEA | 1%; 0.125 W; 100 ppm/K | https://www.vishay.com/docs/20035/dcrcwe3.pdf | Top-side SMD
R_W14 | 1 | 2.49k | Resistor_SMD:R_0805_2012Metric | CRCW08052K49FKEA | 1%; 0.125 W; 100 ppm/K | https://www.vishay.com/docs/20035/dcrcwe3.pdf | Top-side SMD
R_W15 | 1 | 2.49k | Resistor_SMD:R_0805_2012Metric | CRCW08052K49FKEA | 1%; 0.125 W; 100 ppm/K | https://www.vishay.com/docs/20035/dcrcwe3.pdf | Top-side SMD
R_W16 | 1 | 2.49k | Resistor_SMD:R_0805_2012Metric | CRCW08052K49FKEA | 1%; 0.125 W; 100 ppm/K | https://www.vishay.com/docs/20035/dcrcwe3.pdf | Top-side SMD
R_W2 | 1 | 2.49k | Resistor_SMD:R_0805_2012Metric | CRCW08052K49FKEA | 1%; 0.125 W; 100 ppm/K | https://www.vishay.com/docs/20035/dcrcwe3.pdf | Top-side SMD
R_W3 | 1 | 2.49k | Resistor_SMD:R_0805_2012Metric | CRCW08052K49FKEA | 1%; 0.125 W; 100 ppm/K | https://www.vishay.com/docs/20035/dcrcwe3.pdf | Top-side SMD
R_W4 | 1 | 2.49k | Resistor_SMD:R_0805_2012Metric | CRCW08052K49FKEA | 1%; 0.125 W; 100 ppm/K | https://www.vishay.com/docs/20035/dcrcwe3.pdf | Top-side SMD
R_W5 | 1 | 2.49k | Resistor_SMD:R_0805_2012Metric | CRCW08052K49FKEA | 1%; 0.125 W; 100 ppm/K | https://www.vishay.com/docs/20035/dcrcwe3.pdf | Top-side SMD
R_W6 | 1 | 2.49k | Resistor_SMD:R_0805_2012Metric | CRCW08052K49FKEA | 1%; 0.125 W; 100 ppm/K | https://www.vishay.com/docs/20035/dcrcwe3.pdf | Top-side SMD
R_W7 | 1 | 2.49k | Resistor_SMD:R_0805_2012Metric | CRCW08052K49FKEA | 1%; 0.125 W; 100 ppm/K | https://www.vishay.com/docs/20035/dcrcwe3.pdf | Top-side SMD
R_W8 | 1 | 2.49k | Resistor_SMD:R_0805_2012Metric | CRCW08052K49FKEA | 1%; 0.125 W; 100 ppm/K | https://www.vishay.com/docs/20035/dcrcwe3.pdf | Top-side SMD
R_W9 | 1 | 2.49k | Resistor_SMD:R_0805_2012Metric | CRCW08052K49FKEA | 1%; 0.125 W; 100 ppm/K | https://www.vishay.com/docs/20035/dcrcwe3.pdf | Top-side SMD
SW1 | 1 | SW_SPDT | Button_Switch_THT:SW_E-Switch_EG1271_SPDT | EG1271A |  | https://www.e-switch.com/wp-content/uploads/2022/06/EG.pdf | Through-hole assembly
SW2 | 1 | SW_SPDT | Button_Switch_THT:SW_E-Switch_EG1271_SPDT | EG1271A |  | https://www.e-switch.com/wp-content/uploads/2022/06/EG.pdf | Through-hole assembly
SW3 | 1 | LEARN / STOP | Button_Switch_SMD:SW_SPST_B3U-1000P | B3U-1000P |  | https://omronfs.omron.com/en_US/ecb/products/pdf/en-b3u.pdf | Top SMD; not washable: install after any wet cleaning
U1 | 1 | TLV9064IDR | Package_SO:SOIC-14_3.9x8.7mm_P1.27mm | TLV9064IDR |  | https://www.ti.com/lit/ds/symlink/tlv9064.pdf | Top-side SMD
U10 | 1 | MCP4251-104E/SL | Package_SO:SOIC-14_3.9x8.7mm_P1.27mm | MCP4251-104E/SL |  | https://ww1.microchip.com/downloads/aemDocuments/documents/OTH/ProductDocuments/DataSheets/22060b.pdf | Top-side SMD
U11 | 1 | MCP4251-104E/SL | Package_SO:SOIC-14_3.9x8.7mm_P1.27mm | MCP4251-104E/SL |  | https://ww1.microchip.com/downloads/aemDocuments/documents/OTH/ProductDocuments/DataSheets/22060b.pdf | Top-side SMD
U12 | 1 | MCP4251-104E/SL | Package_SO:SOIC-14_3.9x8.7mm_P1.27mm | MCP4251-104E/SL |  | https://ww1.microchip.com/downloads/aemDocuments/documents/OTH/ProductDocuments/DataSheets/22060b.pdf | Top-side SMD
U13 | 1 | MCP4251-104E/SL | Package_SO:SOIC-14_3.9x8.7mm_P1.27mm | MCP4251-104E/SL |  | https://ww1.microchip.com/downloads/aemDocuments/documents/OTH/ProductDocuments/DataSheets/22060b.pdf | Top-side SMD
U14 | 1 | MCP4822-E/SN | Package_SO:SOIC-8_3.9x4.9mm_P1.27mm | MCP4822-E/SN |  | https://ww1.microchip.com/downloads/en/DeviceDoc/20002249B.pdf | Top-side SMD
U15 | 1 | TLV9062IDR | Package_SO:SOIC-8_3.9x4.9mm_P1.27mm | TLV9062IDR |  | https://www.ti.com/lit/ds/symlink/tlv9062.pdf | Top-side SMD
U16 | 1 | ADS1115IDGSR | Package_SO:TSSOP-10_3x3mm_P0.5mm | ADS1115IDGSR |  | https://www.ti.com/lit/ds/symlink/ads1115.pdf | Top-side SMD
U17 | 1 | TLV9064IDR | Package_SO:SOIC-14_3.9x8.7mm_P1.27mm | TLV9064IDR |  | https://www.ti.com/lit/ds/symlink/tlv9064.pdf | Top-side SMD
U18 | 1 | TLV3202AIDR | Package_SO:SOIC-8_3.9x4.9mm_P1.27mm | TLV3202AIDR |  | https://www.ti.com/lit/ds/symlink/tlv3202.pdf | Top-side SMD
U19 | 1 | TPS22918DBVR | Package_TO_SOT_SMD:SOT-23-6 | TPS22918DBVR |  | https://www.ti.com/lit/ds/symlink/tps22918.pdf | Top-side SMD
U2 | 1 | TLV9064IDR | Package_SO:SOIC-14_3.9x8.7mm_P1.27mm | TLV9064IDR |  | https://www.ti.com/lit/ds/symlink/tlv9064.pdf | Top-side SMD
U20 | 1 | LM66100DCKR | Package_TO_SOT_SMD:SOT-363_SC-70-6 | LM66100DCKR |  | https://www.ti.com/lit/ds/symlink/lm66100.pdf | Top-side SMD
U3 | 1 | Arduino_Nano_v3.x | Module:Arduino_Nano | A000005 |  | https://docs.arduino.cc/resources/datasheets/A000005-datasheet.pdf | Fit after SMD reflow; solder module with headers
U4 | 1 | TMUX1133PWR | Package_SO:TSSOP-16_4.4x5mm_P0.65mm | TMUX1133PWR |  | https://www.ti.com/lit/ds/symlink/tmux1133.pdf | Top-side SMD
U5 | 1 | TMUX1133PWR | Package_SO:TSSOP-16_4.4x5mm_P0.65mm | TMUX1133PWR |  | https://www.ti.com/lit/ds/symlink/tmux1133.pdf | Top-side SMD
U6 | 1 | MCP4251-104E/SL | Package_SO:SOIC-14_3.9x8.7mm_P1.27mm | MCP4251-104E/SL |  | https://ww1.microchip.com/downloads/aemDocuments/documents/OTH/ProductDocuments/DataSheets/22060b.pdf | Top-side SMD
U7 | 1 | MCP4251-104E/SL | Package_SO:SOIC-14_3.9x8.7mm_P1.27mm | MCP4251-104E/SL |  | https://ww1.microchip.com/downloads/aemDocuments/documents/OTH/ProductDocuments/DataSheets/22060b.pdf | Top-side SMD
U8 | 1 | MCP4251-104E/SL | Package_SO:SOIC-14_3.9x8.7mm_P1.27mm | MCP4251-104E/SL |  | https://ww1.microchip.com/downloads/aemDocuments/documents/OTH/ProductDocuments/DataSheets/22060b.pdf | Top-side SMD
U9 | 1 | MCP4251-104E/SL | Package_SO:SOIC-14_3.9x8.7mm_P1.27mm | MCP4251-104E/SL |  | https://ww1.microchip.com/downloads/aemDocuments/documents/OTH/ProductDocuments/DataSheets/22060b.pdf | Top-side SMD

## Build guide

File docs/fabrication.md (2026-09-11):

# PCBWay prototype fabrication and assembly

## Generate a package from this repository

Run the simulation suite from README.md, then `python tools/export_manufacturing.py`. It runs KiCad ERC/DRC/parity, checks the exported netlist and BOM/placement population against the manifest, and creates `build/manufacturing/` plus `build/pcbway-gerbers.zip`. The directory contains Gerbers/drill, grouped BOM, top SMD positions, schematic PDF, assembly drawings, check reports and hashes. It must be regenerated after design changes. Source BOM updates use `python tools/generate_bom.py`.

The script refuses an existing destination to prevent mixing releases. Move a package you need to retain elsewhere, or explicitly remove disposable build output before exporting again. When ordering, retain the exact uploaded package and hash list with the order record; do not silently regenerate it under the same order.

## Quote settings and upload sequence

Use the following reviewed preferences; verify actual available options and prices on PCBWay when quoting:

| Setting | Intended selection |
|---|---|
| Board | 106 × 88 mm; two layers |
| Material / thickness | FR-4, 1.6 mm |
| Copper | 1 oz |
| Solder mask | Black, both sides |
| Silkscreen | White, both sides |
| Finish | ENIG |
| Quantity | Last discussed: five boards, two assembled; confirm at order |
| Assembly | Turnkey preferred, including seven through-hole components |

Upload `pcbway-gerbers.zip` to the PCB fabrication quote, not the full source repository. For assembly provide the grouped BOM, positions-smd.csv, assembly-top.svg and schematic.pdf. The bottom guide drawing helps confirm the back silkscreen. Positions are in millimeters using the same KiCad global origin as fabrication exports; all 124 SMD parts are on top.

Review PCBWay's inferred size, layers, holes and silkscreen. Compare its placement/polarity preview with the assembly drawing, particularly IC pin 1, diodes/LEDs, USB connector and Nano orientation. The BOM has exact preferred MPNs, not confirmed stock. Review every substitution and update CAD/manifest/BOM together if accepted.

## Assembly questions to resolve

- B3U-1000P SW3 is not washable: confirm a compatible process or installation after wet cleaning.
- Confirm the classic 5 V A000005 Nano/module and its header supply/installation; do not substitute another Nano family member.
- Confirm assembly of the anchored USB connector, slide switches, LEDs and module in the through-hole operation.
- Retain precision resistor tolerances, mux/op-amp selection, Schottky diode technology and specified footprints.
- Confirm DFM exceptions are limited to the reviewed connector land pattern; do not approve global clearance reductions.

No order is placed yet. Review final sourcing, DFM, quantities, shipping and total price before authorizing payment/order. After ordering, add an order record under docs/bench/ with order ID, date, board revision, Git commit and uploaded file hashes. Current website behavior/pricing must be checked live.

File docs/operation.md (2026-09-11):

# Using the board as a learning demo

This procedure describes the intended interface. It becomes usable only after firmware and bring-up acceptance are complete; there is currently no ready-to-flash demo image.

1. Connect power and serial diagnostics. Wait for firmware to report calibrated initialization and either restored weights or an untrained state. POWER confirms the rail is present, not successful initialization.
2. In manual mode, set the two switches labeled INPUT X1 and INPUT X2. Verify their printed 0/1 positions during first bring-up.
3. Read the PREDICTION LEDs: D_GRN2 represents class 0 and D_GRN1 class 1. These are analog comparator outputs and can show a class before weights or calibration are valid. They do not identify training mode.
4. With trained/restored weights, check 00→0, 01→1, 10→1 and 11→0. Record the measured YP−YN as well as the LED class when debugging marginal results.
5. LEARN/STOP requests training or a phase-boundary stop once the firmware implements it. Training temporarily overrides input switches. After stopping, the firmware restores free-phase DAC commands and manual input control while retaining weights.
6. Save trained weights using the eventual documented firmware command before removing power; digital pots are volatile. Power-cycle and verify restoration before handing the demo to someone else.

The back-side guide summarizes complementary inputs, hidden nodes, differential output and free/nudged learning. Reference designators and test points remain useful for tracing the full schematic. For unexpected behavior, return to bring-up.md: check supply/reference levels, DAC free-phase residual, ADC range/settling, tap readback and input encoding before changing learning parameters.

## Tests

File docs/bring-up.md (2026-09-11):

# Revision B bring-up and firmware requirements

1. Inspect polarity and IC orientation. Power through a current-limited bench source for initial checks. Record USB input, protected input, board supply, current draw and reference voltages. Check the TPS22918 startup waveform and absence of reverse current at USB-C when the Nano USB port powers the board.
2. Initialize all pot chip-select and DAC chip-select pins inactive before starting SPI. Park unused op-amp channels as shown. Keep unused MCU analog inputs as inputs with pull-ups disabled. Manual switches connect through 10k resistors: firmware output drive can override them; define manual and training modes explicitly.
3. Measure V_LOW, V_HIGH and each V_MID. Check with an oscilloscope for oscillation at reference buffers, U15 pump outputs and U17 ADC buffers, both idle and during worst-case weight/input/DAC steps. The DC behavioral model does not prove stability. Determine a measured settling delay before phase sampling.
4. MCP4251 wiper codes are 0..256 inclusive (257 positions), not an 8-bit 0..255-only scale. W and B are tied; use the nominal mapping in `sim/eqprop/network.py`, then calibrate the actual resistor range. The pots are volatile and require initialization at startup.
5. MCP4822 requires gain=2 for its 0..4.096 V nominal range. The free phase requires **measured V_MID_PUMP**, not automatically 2.500 V or code2048. Use `V_DAC = V_MID_PUMP + I_command / (2e-6 A/V)`. Verify polarity by measuring current at several forced load voltages. Measure free-phase residual current for both channels and calibrate DAC zero and gain.
6. Start with beta=1e-6 A/V, matching the revised training default. Limit commanded current using DAC limits and `V_amp=1.5*(V_DAC+V_load)-2*V_MID_PUMP` with measured supply. Do not use the previous 1M transresistance or unbounded nudge commands. Reduce beta if any equilibrium or command leaves the validated range.
7. Configure ADS1115 single-ended channels for H1,H2,YP,YN as shown. Choose a full-scale range that covers the actual voltages. Allow conversion/channel-switch settling; average after the analog circuit has settled. Calibrate channel offsets. Keep SPI transfers outside equilibrium sampling windows.
8. Verify all four XOR inputs and complementary mux outputs before training. Train, read back taps, power-cycle and restore them, and verify classification with the actual analog hysteresis thresholds. Repeat at intended supply extremes and temperature range before committing to a larger assembly batch.

This is a prototype validation procedure, not a statement that these physical checks have already passed. No firmware source was present in the reviewed workspace, so the interface changes are documented rather than claimed implemented on a microcontroller.

## B.1 learn/stop button

SW3 connects Nano A6 to GND; R_BUTTON1 supplies the external pull-up. Read it as an analog input, not digitalRead or INPUT_PULLUP. Follow the debounce, phase-boundary stop, and assembly requirements in [usability revision](usability-revision.md). This is a firmware requirement, not completed MCU code.

## Startup, sampling and calibration details from pre-commit review

At reset, ignore prediction LEDs until initialization and settling finish. The DAC powers up shut down; shutdown presents about 500 kohm to ground and is **not** the calibrated free phase. Set all CS outputs high before enabling SPI, then program both DAC channels active at their calibrated zero-current codes before accepting samples. The grounded LDAC pin means A and B update sequentially: finish both writes, then settle before measurement. Stop training by restoring active zero-current commands, not by shutting down the DAC. Gain=2 gives nominal 1 mV/code; code 4095 produces 4.095 V, not 4.096 V. Calibrate actual transfer errors. [Microchip MCP4822, sections 4–5](https://ww1.microchip.com/downloads/en/DeviceDoc/20002249B.pdf)

V_MID_PUMP is accessible at TP5 but is not wired to an ADC channel. For initial firmware, enter its DMM-measured value and calibrate both pumps at the intended supply. Repeat calibration after changing the supply source or observing rail drift. A stored fixed DAC zero does not automatically follow the ratiometric midrail; do not claim automatic tracking. Verify residual current over the intended supply variation before unattended demos.

Explicitly select ADS1115 PGA ±4.096 V for the nominal midrail measurements: reset/default ±2.048 V clips them. This setting gives 125 uV/code. Use ±6.144 V if measured inputs can exceed 4.096 V; a wider PGA range does not permit inputs outside GND..VDD. Start a single-shot conversion after configuring each channel and wait for completion before reading it. Hold inputs, weights and both nudge commands constant for the entire four-channel scan; this ADC multiplexes channels rather than sampling simultaneously. Analog settling precedes the conversion. [TI ADS1115, full-scale-range table and configuration register](https://www.ti.com/lit/ds/symlink/ads1115.pdf)

Keep fractional weight-update accumulators in firmware and quantize the requested conductances when programming taps. Rounding each small learning increment independently may discard it. Characterize this policy in a hardware-in-the-loop training test; the existing continuous-training/final-quantization result does not validate online finite-tap training.

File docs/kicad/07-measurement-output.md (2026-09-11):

# Revision B: measurement output

Use the native hierarchical schematic. Older wiring instructions do not apply to this revision. See [design](../design.md) and [bring-up](../bring-up.md).

| Reference | Value / MPN | Pin-to-net map |
|---|---|---|
| TP3 | TestPoint / PCB copper feature (no component) | 1=V_MID_H1 |
| TP1 | TestPoint / PCB copper feature (no component) | 1=V_LOW |
| R_LED_G1 | 2.2k / CRCW08052K20FKEA | 1=D_GRN1_A, 2=+5V |
| TP11 | TestPoint / PCB copper feature (no component) | 1=YN |
| TP9 | TestPoint / PCB copper feature (no component) | 1=DAC_OUTB |
| C17 | 100nF / C0805C104K5RACTU | 1=+5V, 2=GND |
| R20 | 4.7k / CRCW08054K70FKEA | 1=+5V, 2=I2C_SDA |
| TP10 | TestPoint / PCB copper feature (no component) | 1=YP |
| C11 | 1nF / C0805C102J5GACTU | 1=H2_ADC, 2=GND |
| C10 | 1nF / C0805C102J5GACTU | 1=H1_ADC, 2=GND |
| TP8 | TestPoint / PCB copper feature (no component) | 1=DAC_OUTA |
| TP6 | TestPoint / PCB copper feature (no component) | 1=H1 |
| C7 | 100nF / C0805C104K5RACTU | 1=+5V, 2=GND |
| C5 | 100nF / C0805C104K5RACTU | 1=+5V, 2=GND |
| R_LED_R1 | 2.2k / CRCW08052K20FKEA | 1=D_GRN2_A, 2=+5V |
| TP5 | TestPoint / PCB copper feature (no component) | 1=V_MID_PUMP |
| U16 | ADS1115IDGSR / ADS1115IDGSR | 1=GND, 3=GND, 4=H1_ADC, 5=H2_ADC, 6=YP_ADC, 7=YN_ADC, 8=+5V, 9=I2C_SDA, 10=I2C_SCL |
| R21 | 4.7k / CRCW08054K70FKEA | 1=+5V, 2=I2C_SCL |
| TP7 | TestPoint / PCB copper feature (no component) | 1=H2 |
| TP4 | TestPoint / PCB copper feature (no component) | 1=V_MID_H2 |
| TP2 | TestPoint / PCB copper feature (no component) | 1=V_HIGH |
| U17 | TLV9064IDR / TLV9064IDR | 1=H1_BUF, 2=H1_BUF, 3=H1, 4=+5V, 5=H2, 6=H2_BUF, 7=H2_BUF, 8=YP_BUF, 9=YP_BUF, 10=YP, 11=GND, 12=YN, 13=YN_BUF, 14=YN_BUF |
| R_ADC1 | 100 / CRCW0805100RFKEA | 1=H1_BUF, 2=H1_ADC |
| R_ADC2 | 100 / CRCW0805100RFKEA | 1=H2_BUF, 2=H2_ADC |
| R_ADC3 | 100 / CRCW0805100RFKEA | 1=YP_BUF, 2=YP_ADC |
| C27 | 1nF / C0805C102J5GACTU | 1=YP_ADC, 2=GND |
| R_ADC4 | 100 / CRCW0805100RFKEA | 1=YN_BUF, 2=YN_ADC |
| C28 | 1nF / C0805C102J5GACTU | 1=YN_ADC, 2=GND |
| R_D1 | 100k / TNPW0805100KBEEA | 1=YP_BUF, 2=PRED_PLUS |
| R_D2 | 100k / TNPW0805100KBEEA | 1=V_MID_PUMP, 2=PRED_PLUS |
| R_D3 | 100k / TNPW0805100KBEEA | 1=YN_BUF, 2=PRED_MINUS |
| R_D4 | 100k / TNPW0805100KBEEA | 1=PRED, 2=PRED_MINUS |
| R_TH1 | 4.99k / TNPW08054K99BEEA | 1=+5V, 2=THRESHOLD |
| R_TH2 | 5.62k / TNPW08055K62BEEA | 1=THRESHOLD, 2=GND |
| U18 | TLV3202AIDR / TLV3202AIDR | 1=D_GRN1_K, 2=PRED, 3=THRESHOLD_HYS, 4=GND, 5=V_MID_PUMP, 6=D_GRN1_K, 7=D_GRN2_K, 8=+5V |
| TP12 | TestPoint / PCB copper feature (no component) | 1=GND |
| TP13 | TestPoint / PCB copper feature (no component) | 1=+5V |
| TP14 | TestPoint / PCB copper feature (no component) | 1=GND |
| TP15 | TestPoint / PCB copper feature (no component) | 1=PRED |
| TP16 | TestPoint / PCB copper feature (no component) | 1=THRESHOLD |
| R_HYS1 | 10k / CRCW080510K0FKEA | 1=THRESHOLD, 2=THRESHOLD_HYS |
| R_HYS2 | 2M / CRCW08052M00FKEA | 1=D_GRN1_K, 2=THRESHOLD_HYS |
| C31 | 100nF / C0805C104K5RACTU | 1=THRESHOLD, 2=GND |

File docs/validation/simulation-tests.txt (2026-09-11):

...............................................                          [100%]
47 passed in 8.96s

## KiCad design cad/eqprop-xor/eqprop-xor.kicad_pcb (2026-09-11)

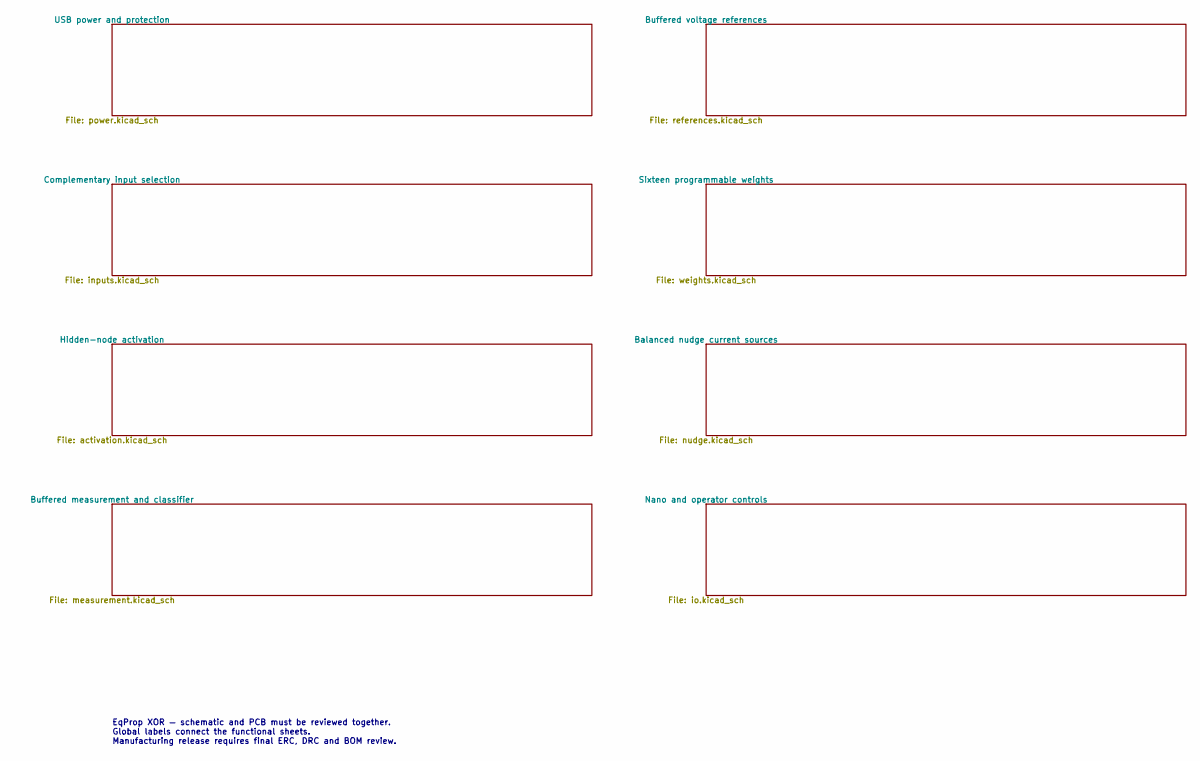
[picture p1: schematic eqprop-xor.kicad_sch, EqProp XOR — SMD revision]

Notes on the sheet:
EqProp XOR — schematic and PCB must be reviewed together. Global labels connect the functional sheets. Manufacturing release requires final ERC, DRC and BOM review.

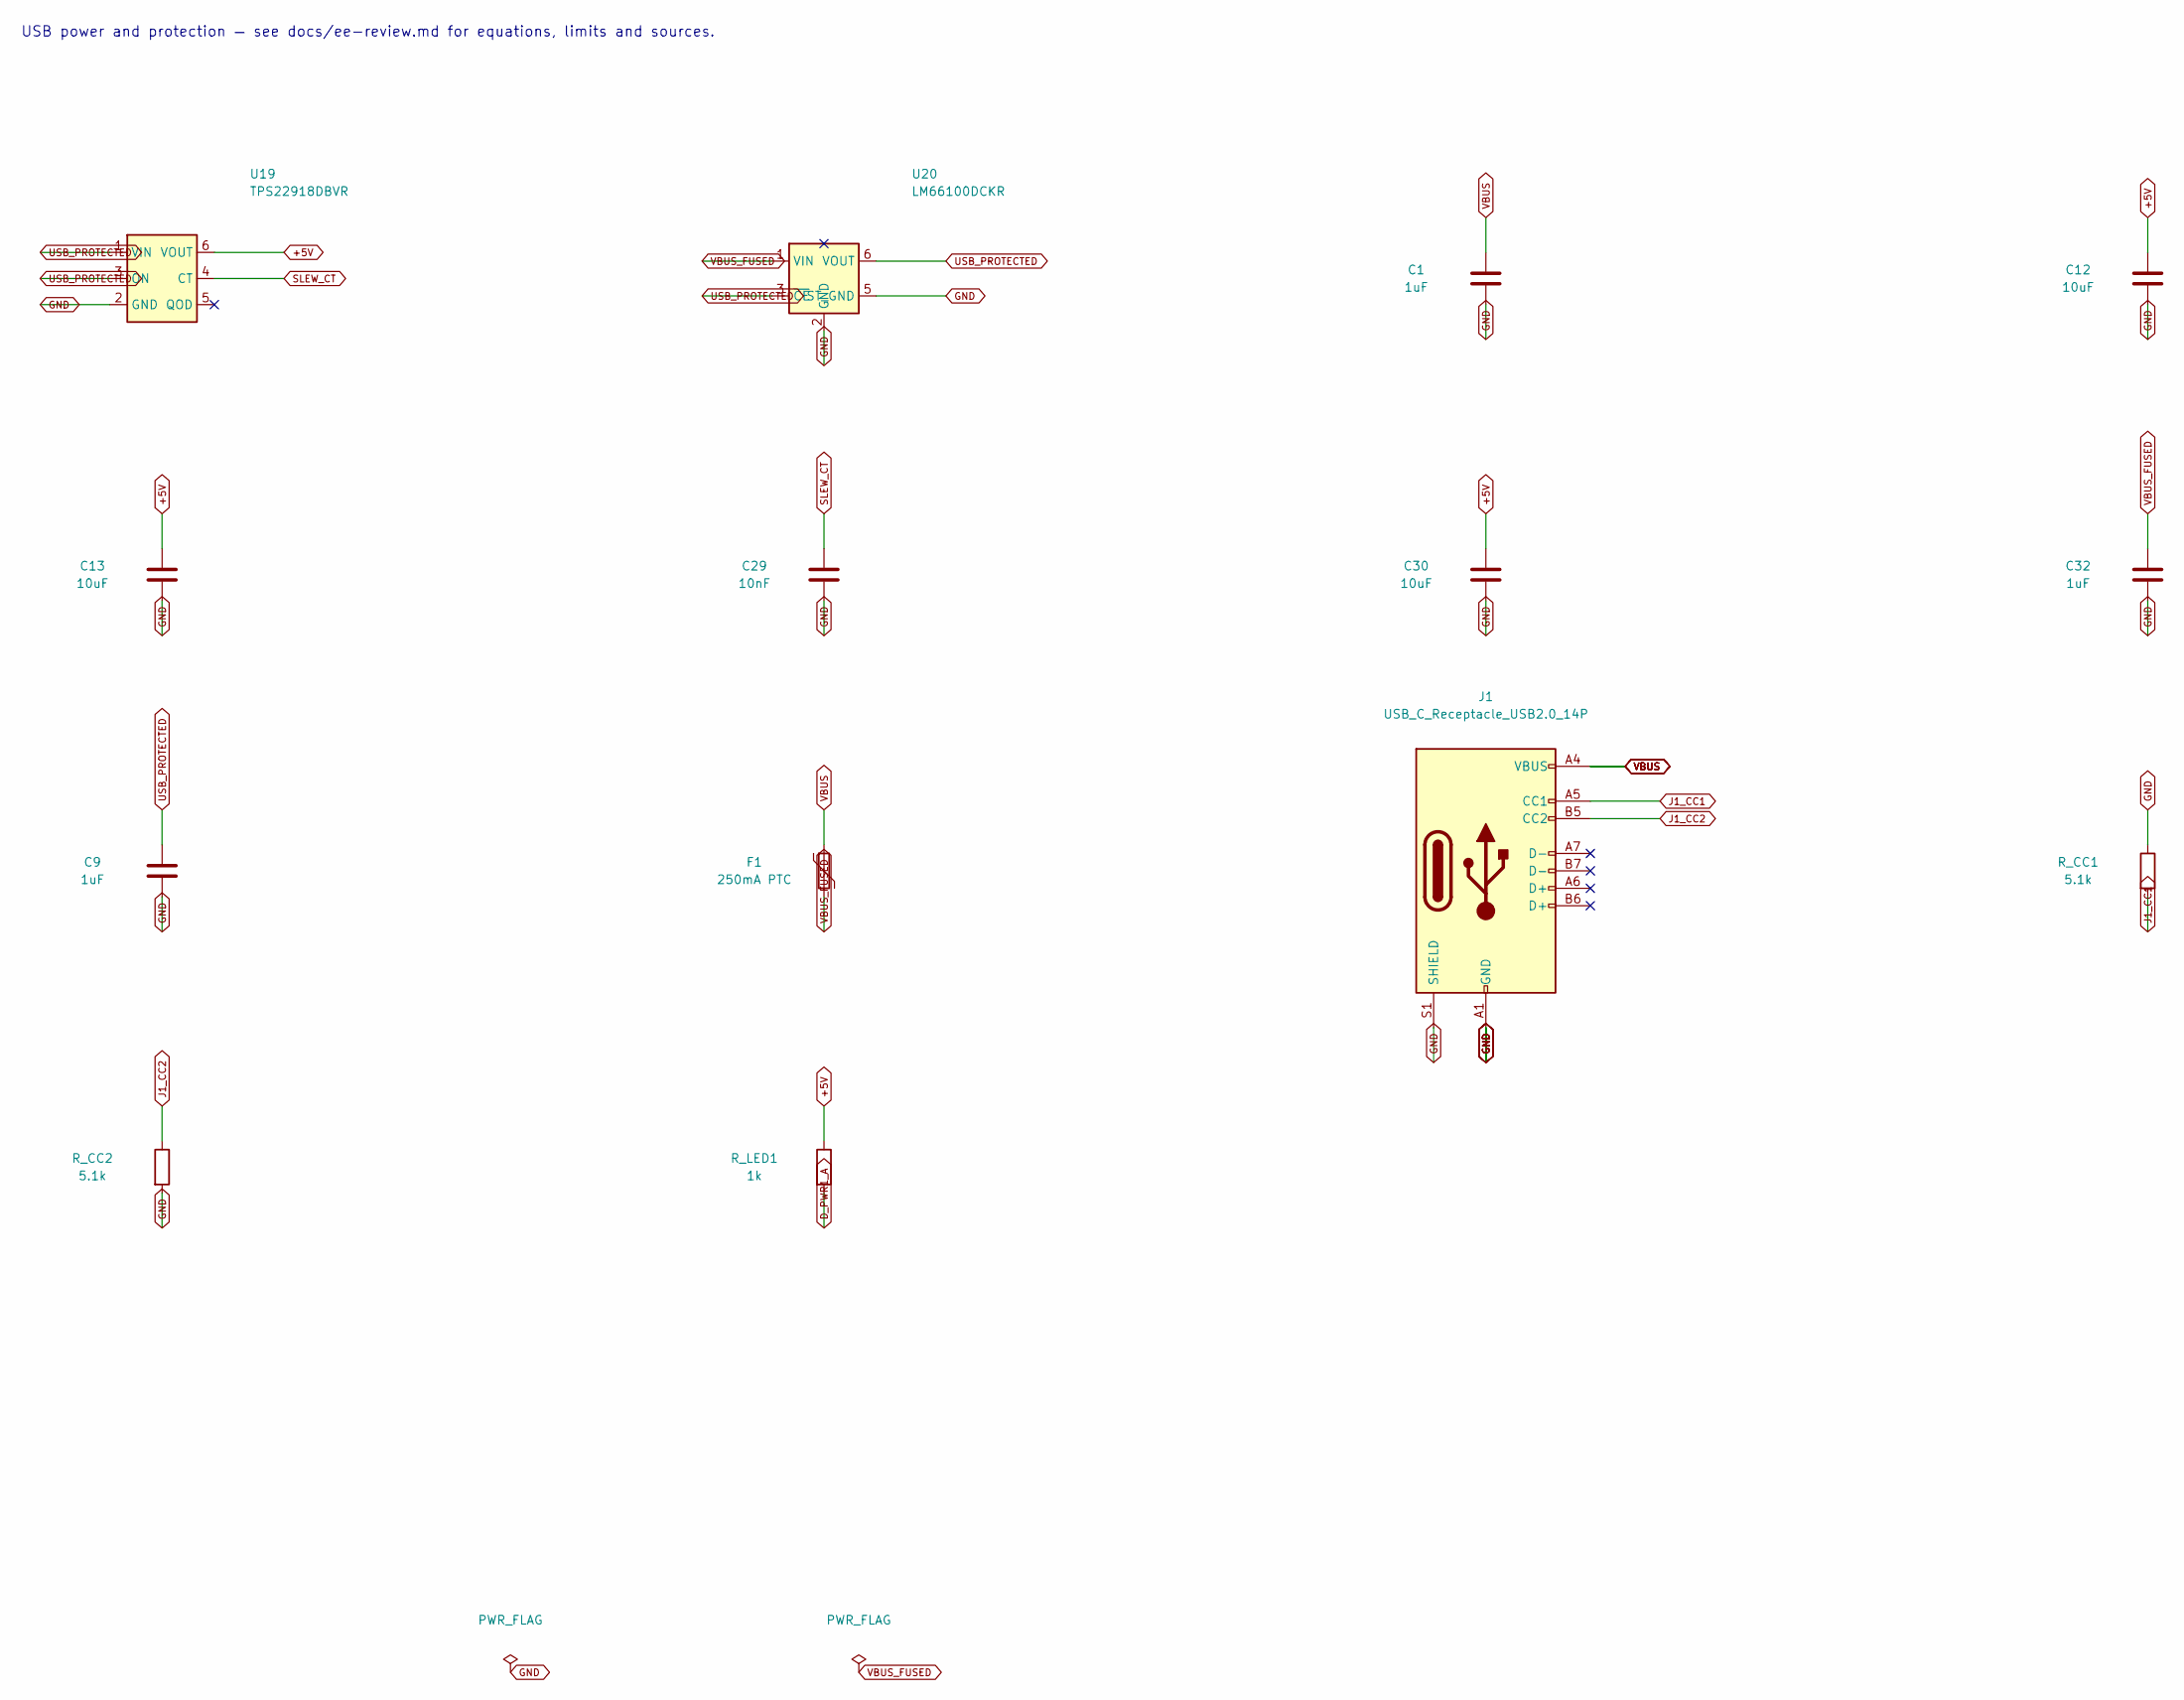
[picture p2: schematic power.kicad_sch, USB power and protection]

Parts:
C1, C9, C32: 1uF; C_0805_2012Metric; MPN C0805C105K4RACTU
C12, C13, C30: 10uF; C_0805_2012Metric; MPN C0805C106K8PACTU
C29: 10nF; C_0805_2012Metric; MPN C0805C103K5RACTU
F1: 250mA PTC; Fuse_1206_3216Metric; MPN MF-NSMF025X-2
J1: USB_C_Receptacle_USB2.0_14P; USB4085_Edge; MPN USB4085-GF-A
R_CC1, R_CC2: 5.1k; R_0805_2012Metric; Tolerance 1%; MPN CRCW08055K10FKEA
R_LED1: 1k; R_0805_2012Metric; Tolerance 1%; MPN CRCW08051K00FKEA
U19: TPS22918DBVR; SOT-23-6; MPN TPS22918DBVR
U20: LM66100DCKR; SOT-363_SC-70-6; MPN LM66100DCKR

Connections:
+5V: C12.1, C13.1, C30.1, R_LED1.1, U19.6 (VOUT); also elsewhere on the board
D_PWR1_A: R_LED1.2; also elsewhere on the board
GND: C1.2, C9.2, C12.2, C13.2, C29.2, C30.2, C32.2, J1.A1 (GND), J1.A12 (GND), J1.B1 (GND), J1.B12 (GND), J1.S1 (SHIELD), R_CC1.1, R_CC2.2, U19.2 (GND), U20.2 (GND), U20.5 (ST_GND); also elsewhere on the board
J1_CC1: J1.A5 (CC1), R_CC1.2
J1_CC2: J1.B5 (CC2), R_CC2.1
SLEW_CT: C29.1, U19.4 (CT)
USB_PROTECTED: C9.1, U19.1 (VIN), U19.3 (ON), U20.3 (~CE), U20.6 (VOUT)
VBUS: C1.1, F1.1, J1.A4 (VBUS), J1.A9 (VBUS), J1.B4 (VBUS), J1.B9 (VBUS)
VBUS_FUSED: C32.1, F1.2, U20.1 (VIN)

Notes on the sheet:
USB power and protection — see docs/ee-review.md for equations, limits and sources.

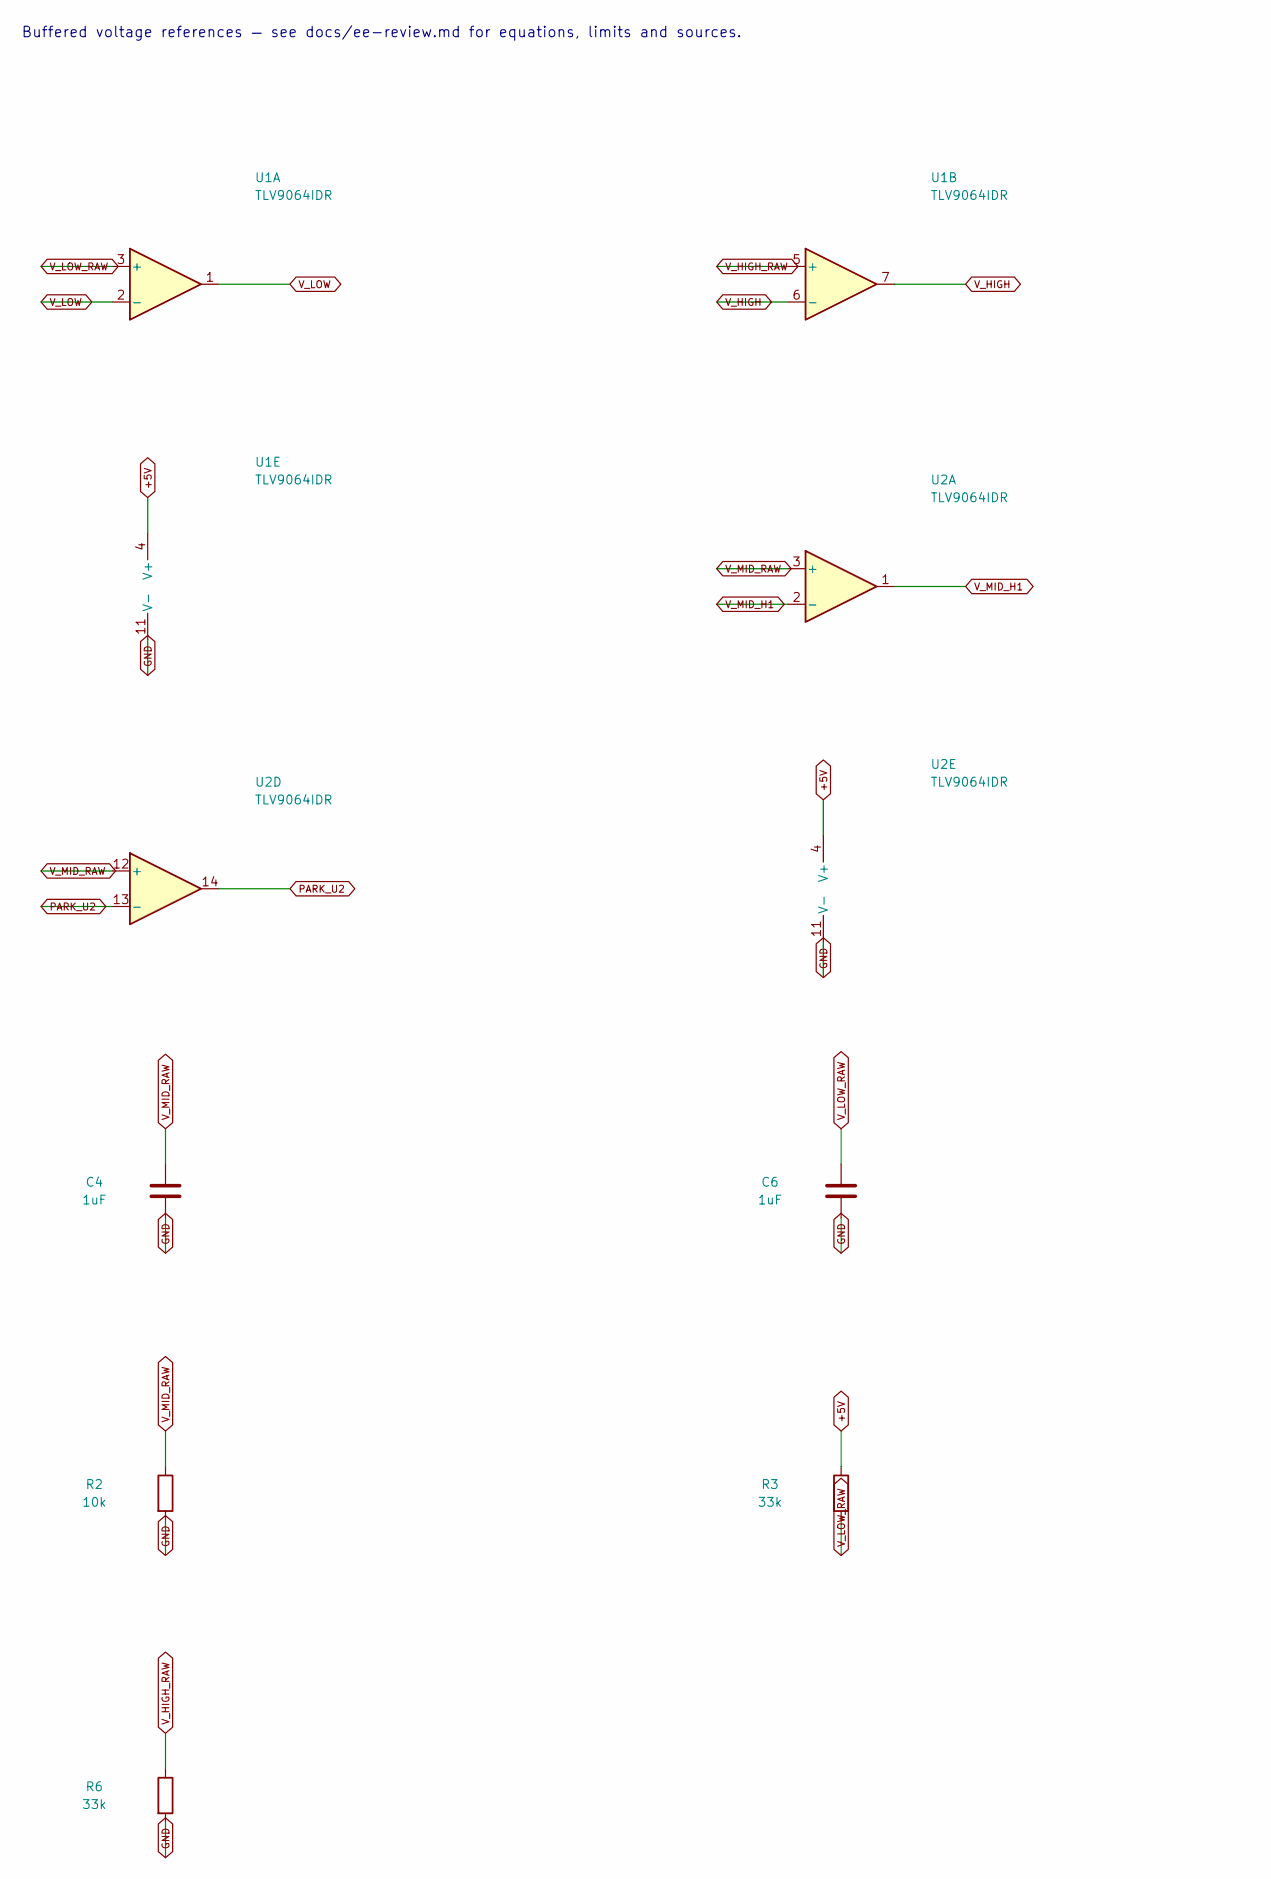
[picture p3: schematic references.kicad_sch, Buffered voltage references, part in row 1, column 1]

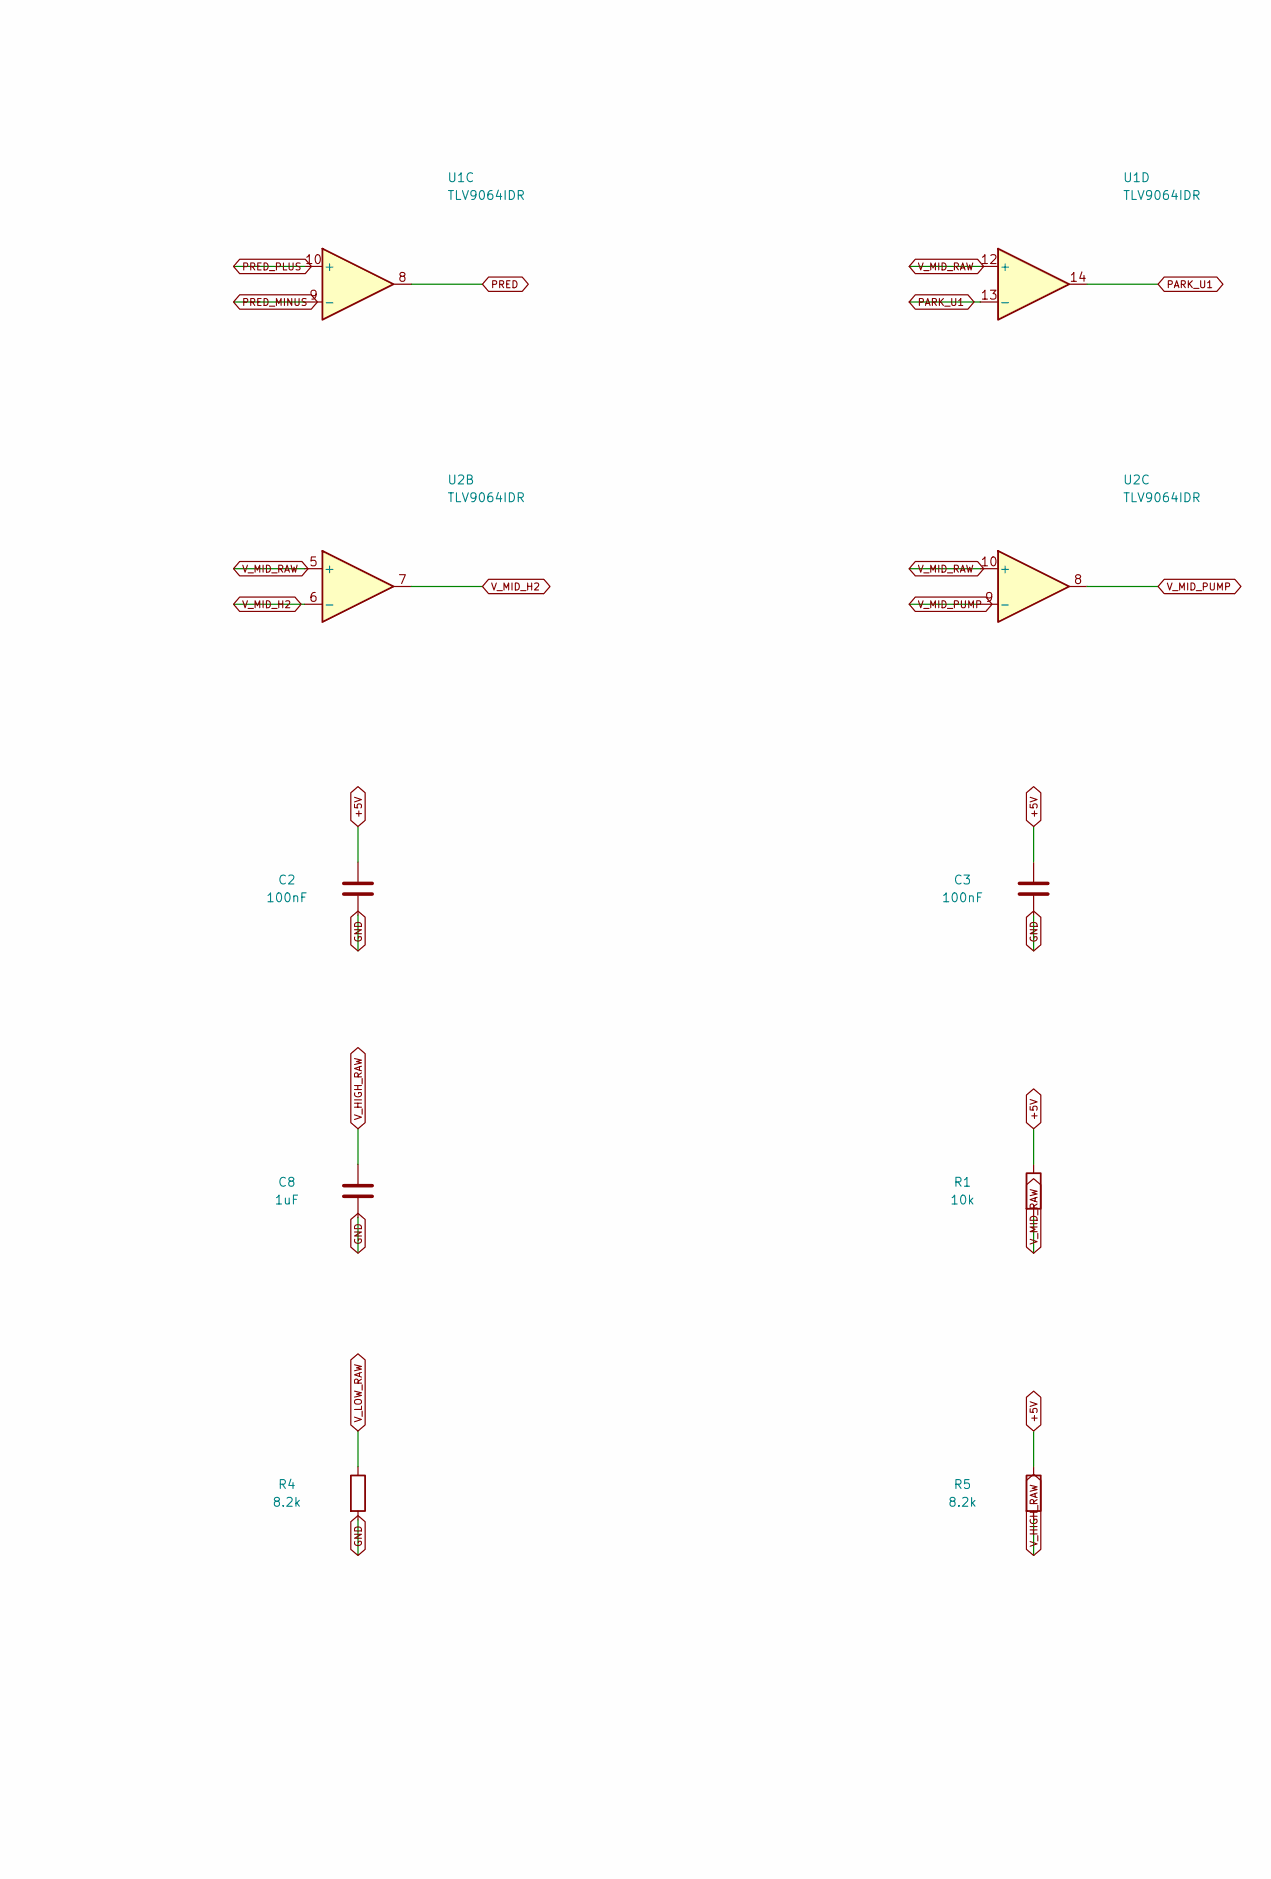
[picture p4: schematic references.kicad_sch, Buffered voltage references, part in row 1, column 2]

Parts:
C2, C3: 100nF; C_0805_2012Metric; MPN C0805C104K5RACTU
C4, C6, C8: 1uF; C_0805_2012Metric; MPN C0805C105K4RACTU
R1, R2: 10k; R_0805_2012Metric; Tolerance 0.1%; MPN TNPW080510K0BEEA
R3, R6: 33k; R_0805_2012Metric; Tolerance 0.1%; MPN TNPW080533K0BEEA
R4, R5: 8.2k; R_0805_2012Metric; Tolerance 0.1%; MPN TNPW08058K20BEEA
U1, U2: TLV9064IDR; SOIC-14_3.9x8.7mm_P1.27mm; MPN TLV9064IDR

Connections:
+5V: C2.1, C3.1, R1.1, R3.1, R5.1, U1.4 (V+), U2.4 (V+); also elsewhere on the board
GND: C2.2, C3.2, C4.2, C6.2, C8.2, R2.2, R4.2, R6.2, U1.11 (V-), U2.11 (V-); also elsewhere on the board
PARK_U1: U1.13 (-), U1.14
PARK_U2: U2.13 (-), U2.14
PRED: U1.8; also elsewhere on the board
PRED_MINUS: U1.9 (-); also elsewhere on the board
PRED_PLUS: U1.10 (+); also elsewhere on the board
V_HIGH: U1.6 (-), U1.7; also elsewhere on the board
V_HIGH_RAW: C8.1, R5.2, R6.1, U1.5 (+)
V_LOW: U1.1, U1.2 (-); also elsewhere on the board
V_LOW_RAW: C6.1, R3.2, R4.1, U1.3 (+)
V_MID_H1: U2.1, U2.2 (-); also elsewhere on the board
V_MID_H2: U2.6 (-), U2.7; also elsewhere on the board
V_MID_PUMP: U2.8, U2.9 (-); also elsewhere on the board
V_MID_RAW: C4.1, R1.2, R2.1, U1.12 (+), U2.3 (+), U2.5 (+), U2.10 (+), U2.12 (+)

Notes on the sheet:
Buffered voltage references — see docs/ee-review.md for equations, limits and sources.

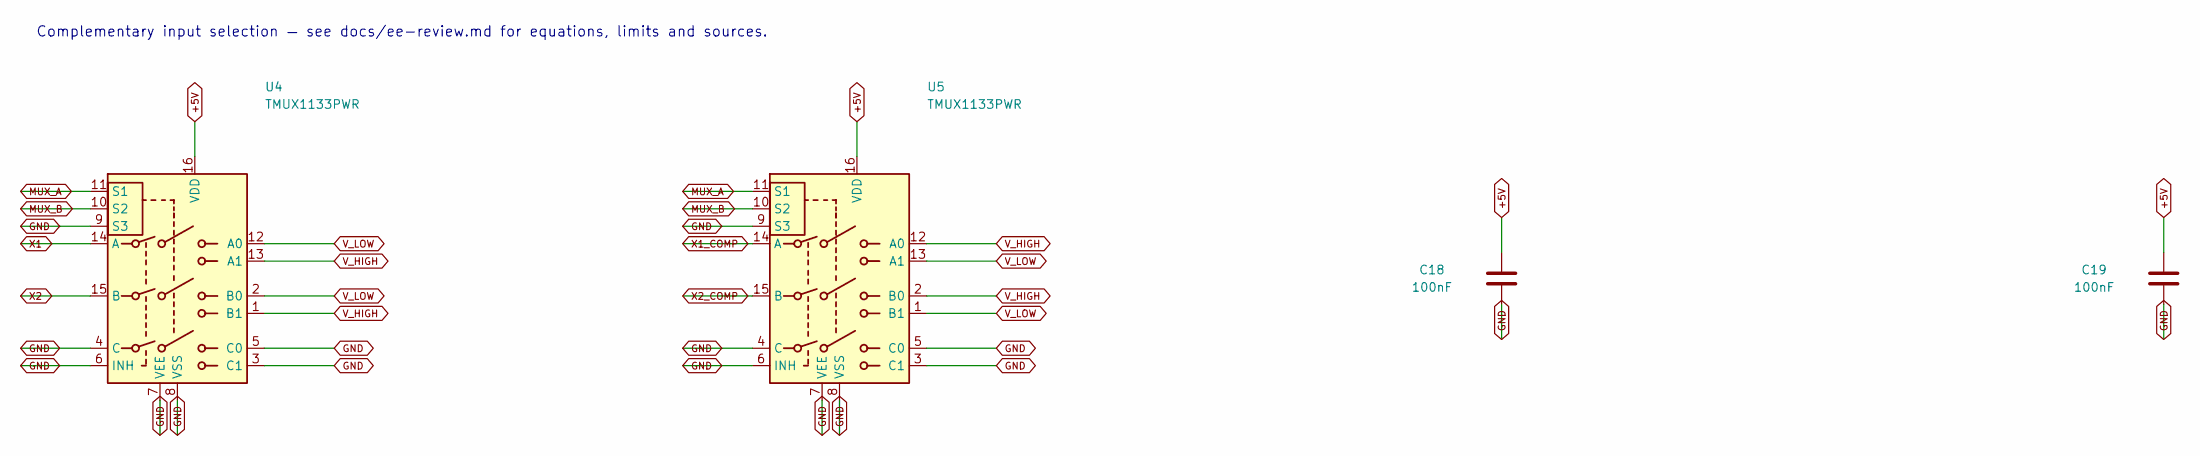
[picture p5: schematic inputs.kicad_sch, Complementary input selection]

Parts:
C18, C19: 100nF; C_0805_2012Metric; MPN C0805C104K5RACTU
U4, U5: TMUX1133PWR; TSSOP-16_4.4x5mm_P0.65mm; MPN TMUX1133PWR

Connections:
+5V: C18.1, C19.1, U4.16 (VDD), U5.16 (VDD); also elsewhere on the board
GND: C18.2, C19.2, U4.3 (C1), U4.4 (C), U4.5 (C0), U4.6 (INH), U4.7 (VEE), U4.8 (VSS), U4.9 (S3), U5.3 (C1), U5.4 (C), U5.5 (C0), U5.6 (INH), U5.7 (VEE), U5.8 (VSS), U5.9 (S3); also elsewhere on the board
MUX_A: U4.11 (S1), U5.11 (S1); also elsewhere on the board
MUX_B: U4.10 (S2), U5.10 (S2); also elsewhere on the board
V_HIGH: U4.1 (B1), U4.13 (A1), U5.2 (B0), U5.12 (A0); also elsewhere on the board
V_LOW: U4.2 (B0), U4.12 (A0), U5.1 (B1), U5.13 (A1); also elsewhere on the board
X1: U4.14 (A); also elsewhere on the board
X1_COMP: U5.14 (A); also elsewhere on the board
X2: U4.15 (B); also elsewhere on the board
X2_COMP: U5.15 (B); also elsewhere on the board

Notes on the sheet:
Complementary input selection — see docs/ee-review.md for equations, limits and sources.

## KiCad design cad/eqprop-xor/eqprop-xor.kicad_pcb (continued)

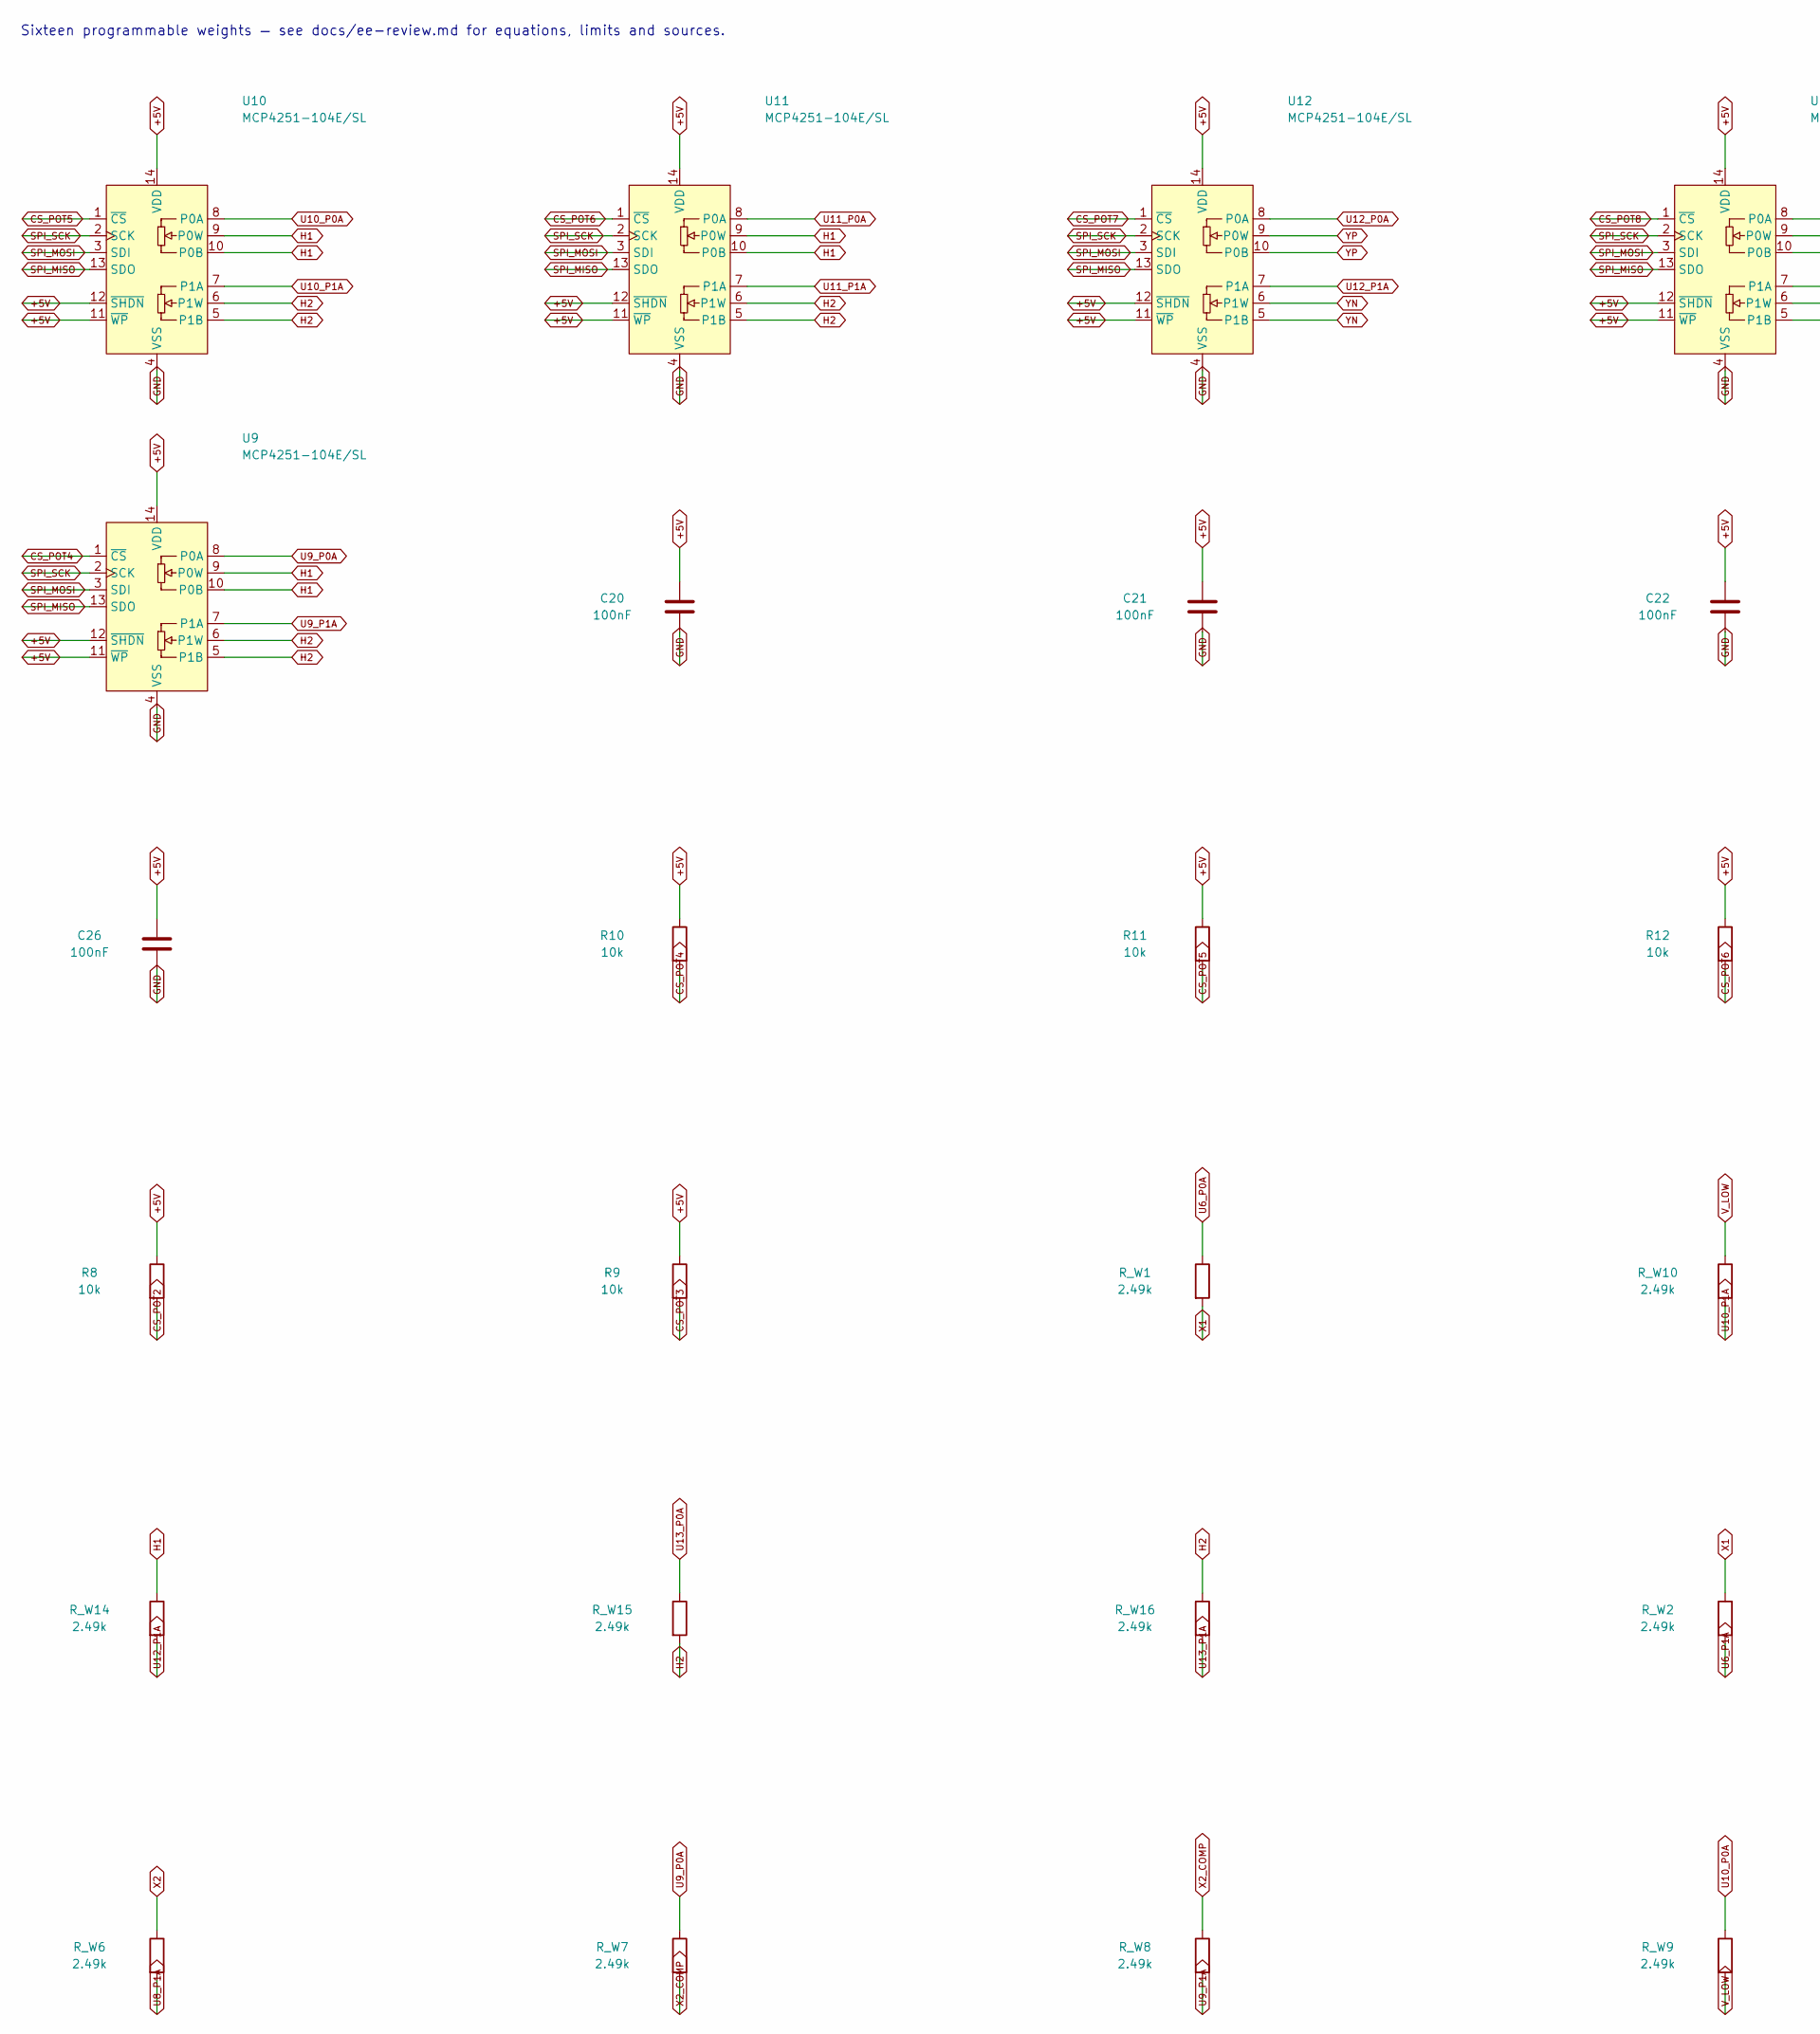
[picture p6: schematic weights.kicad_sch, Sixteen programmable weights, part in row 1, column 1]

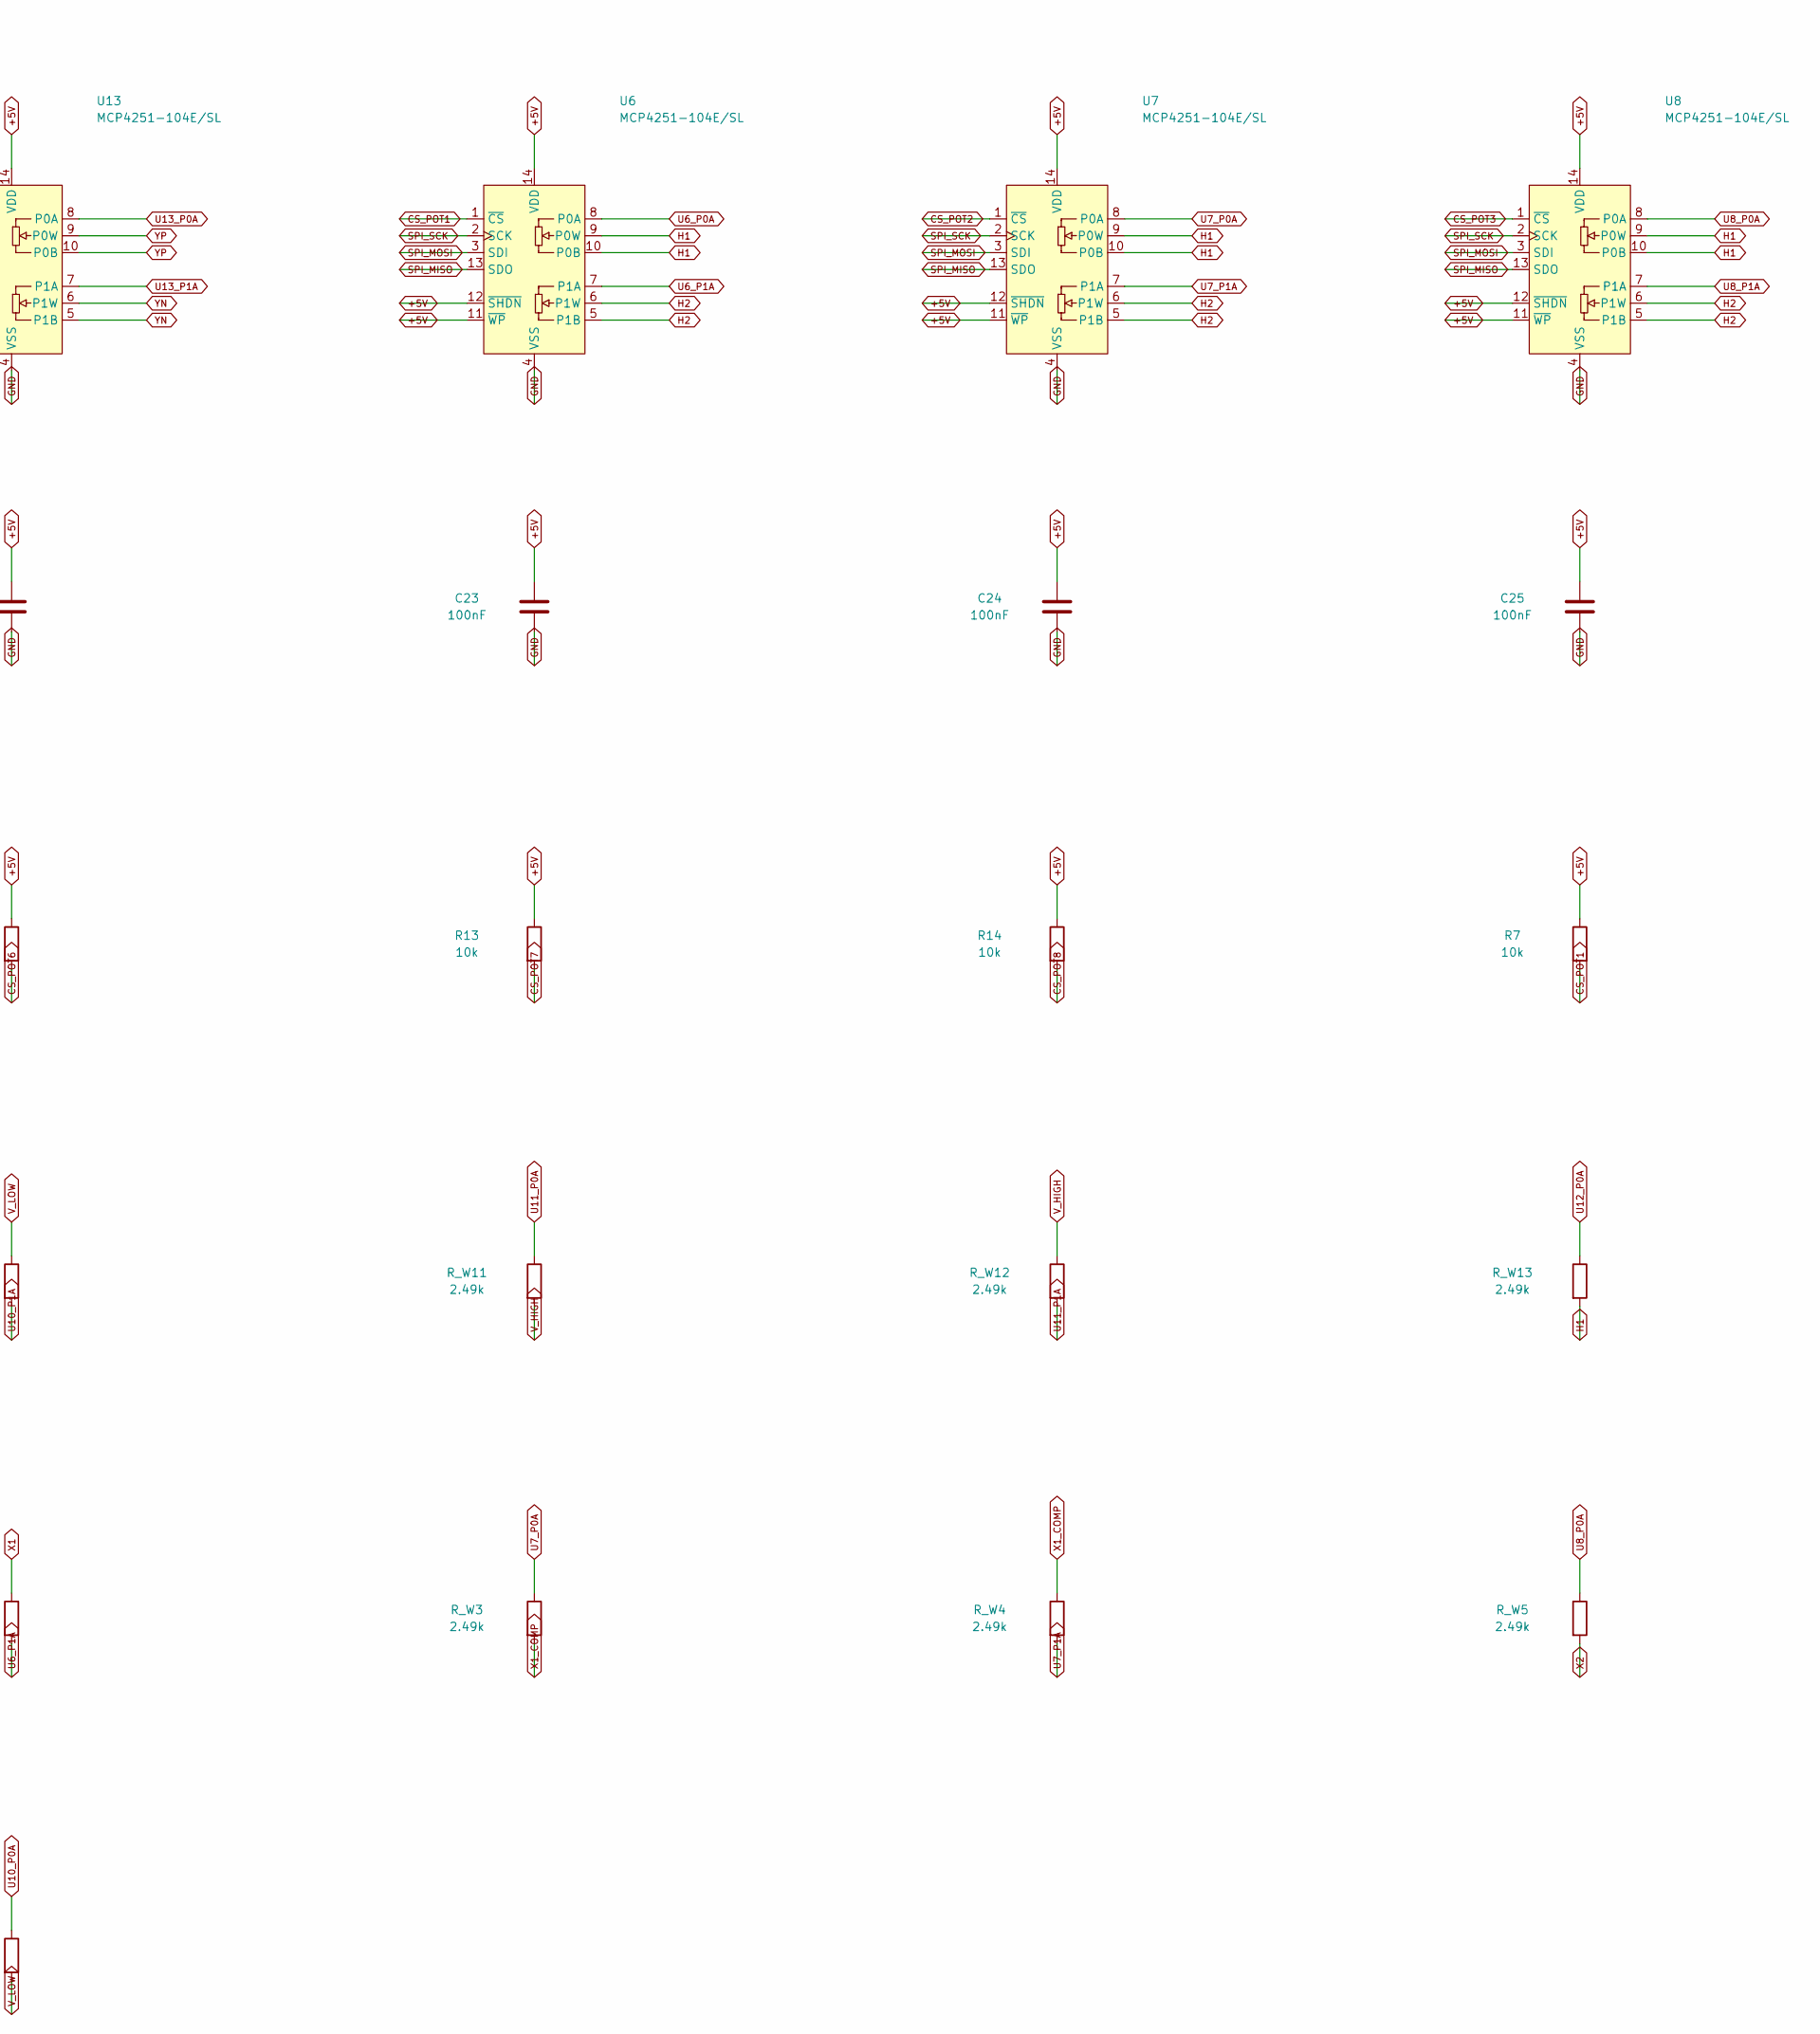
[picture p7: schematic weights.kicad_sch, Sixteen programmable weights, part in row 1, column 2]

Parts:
C20, C21, C22, C23, C24, C25, C26: 100nF; C_0805_2012Metric; MPN C0805C104K5RACTU
R7, R8, R9, R10, R11, R12, R13, R14: 10k; R_0805_2012Metric; Tolerance 1%; MPN CRCW080510K0FKEA
R_W1, R_W2, R_W3, R_W4, R_W5, R_W6, R_W7, R_W8, R_W9, R_W10, R_W11, R_W12, R_W13, R_W14, R_W15, R_W16: 2.49k; R_0805_2012Metric; Tolerance 1%; MPN CRCW08052K49FKEA
U6, U7, U8, U9, U10, U11, U12, U13: MCP4251-104E/SL; SOIC-14_3.9x8.7mm_P1.27mm; MPN MCP4251-104E/SL

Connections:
+5V: C20.1, C21.1, C22.1, C23.1, C24.1, C25.1, C26.1, R7.1, R8.1, R9.1, R10.1, R11.1, R12.1, R13.1, R14.1, U6.11 (~WP), U6.12 (~SHDN), U6.14 (VDD), U7.11 (~WP), U7.12 (~SHDN), U7.14 (VDD), U8.11 (~WP), U8.12 (~SHDN), U8.14 (VDD), U9.11 (~WP), U9.12 (~SHDN), U9.14 (VDD), U10.11 (~WP), U10.12 (~SHDN), U10.14 (VDD), U11.11 (~WP), U11.12 (~SHDN), U11.14 (VDD), U12.11 (~WP), U12.12 (~SHDN), U12.14 (VDD), U13.11 (~WP), U13.12 (~SHDN), U13.14 (VDD); also elsewhere on the board
CS_POT1: R7.2, U6.1 (~CS); also elsewhere on the board
CS_POT2: R8.2, U7.1 (~CS); also elsewhere on the board
CS_POT3: R9.2, U8.1 (~CS); also elsewhere on the board
CS_POT4: R10.2, U9.1 (~CS); also elsewhere on the board
CS_POT5: R11.2, U10.1 (~CS); also elsewhere on the board
CS_POT6: R12.2, U11.1 (~CS); also elsewhere on the board
CS_POT7: R13.2, U12.1 (~CS); also elsewhere on the board
CS_POT8: R14.2, U13.1 (~CS); also elsewhere on the board
GND: C20.2, C21.2, C22.2, C23.2, C24.2, C25.2, C26.2, U6.4 (VSS), U7.4 (VSS), U8.4 (VSS), U9.4 (VSS), U10.4 (VSS), U11.4 (VSS), U12.4 (VSS), U13.4 (VSS); also elsewhere on the board
H1: R_W13.2, R_W14.1, U6.9 (P0W), U6.10 (P0B), U7.9 (P0W), U7.10 (P0B), U8.9 (P0W), U8.10 (P0B), U9.9 (P0W), U9.10 (P0B), U10.9 (P0W), U10.10 (P0B), U11.9 (P0W), U11.10 (P0B); also elsewhere on the board
H2: R_W15.2, R_W16.1, U6.5 (P1B), U6.6 (P1W), U7.5 (P1B), U7.6 (P1W), U8.5 (P1B), U8.6 (P1W), U9.5 (P1B), U9.6 (P1W), U10.5 (P1B), U10.6 (P1W), U11.5 (P1B), U11.6 (P1W); also elsewhere on the board
SPI_MISO: U6.13 (SDO), U7.13 (SDO), U8.13 (SDO), U9.13 (SDO), U10.13 (SDO), U11.13 (SDO), U12.13 (SDO), U13.13 (SDO); also elsewhere on the board
SPI_MOSI: U6.3 (SDI), U7.3 (SDI), U8.3 (SDI), U9.3 (SDI), U10.3 (SDI), U11.3 (SDI), U12.3 (SDI), U13.3 (SDI); also elsewhere on the board
SPI_SCK: U6.2 (SCK), U7.2 (SCK), U8.2 (SCK), U9.2 (SCK), U10.2 (SCK), U11.2 (SCK), U12.2 (SCK), U13.2 (SCK); also elsewhere on the board
U6_P0A: R_W1.1, U6.8 (P0A)
U6_P1A: R_W2.2, U6.7 (P1A)
U7_P0A: R_W3.1, U7.8 (P0A)
U7_P1A: R_W4.2, U7.7 (P1A)
U8_P0A: R_W5.1, U8.8 (P0A)
U8_P1A: R_W6.2, U8.7 (P1A)
U9_P0A: R_W7.1, U9.8 (P0A)
U9_P1A: R_W8.2, U9.7 (P1A)
U10_P0A: R_W9.1, U10.8 (P0A)
U10_P1A: R_W10.2, U10.7 (P1A)
U11_P0A: R_W11.1, U11.8 (P0A)
U11_P1A: R_W12.2, U11.7 (P1A)
U12_P0A: R_W13.1, U12.8 (P0A)
U12_P1A: R_W14.2, U12.7 (P1A)
U13_P0A: R_W15.1, U13.8 (P0A)
U13_P1A: R_W16.2, U13.7 (P1A)
V_HIGH: R_W11.2, R_W12.1; also elsewhere on the board
V_LOW: R_W9.2, R_W10.1; also elsewhere on the board
X1: R_W1.2, R_W2.1; also elsewhere on the board
X1_COMP: R_W3.2, R_W4.1; also elsewhere on the board
X2: R_W5.2, R_W6.1; also elsewhere on the board
X2_COMP: R_W7.2, R_W8.1; also elsewhere on the board
YN: U12.5 (P1B), U12.6 (P1W), U13.5 (P1B), U13.6 (P1W); also elsewhere on the board
YP: U12.9 (P0W), U12.10 (P0B), U13.9 (P0W), U13.10 (P0B); also elsewhere on the board

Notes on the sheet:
Sixteen programmable weights — see docs/ee-review.md for equations, limits and sources.

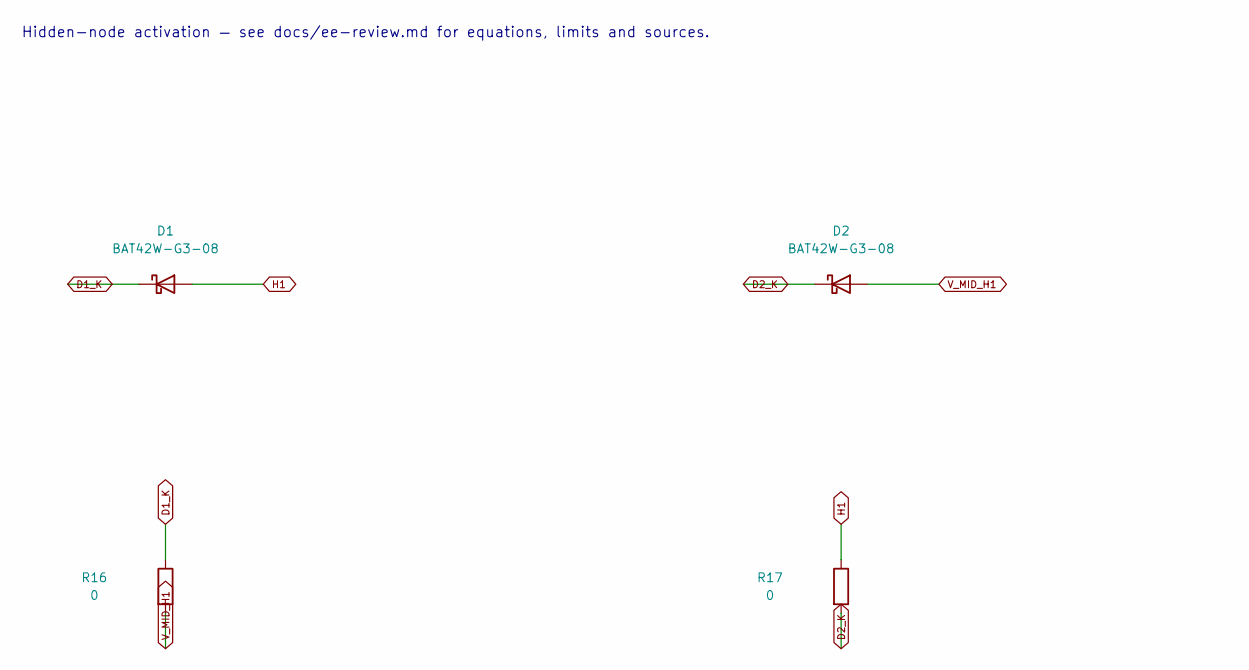
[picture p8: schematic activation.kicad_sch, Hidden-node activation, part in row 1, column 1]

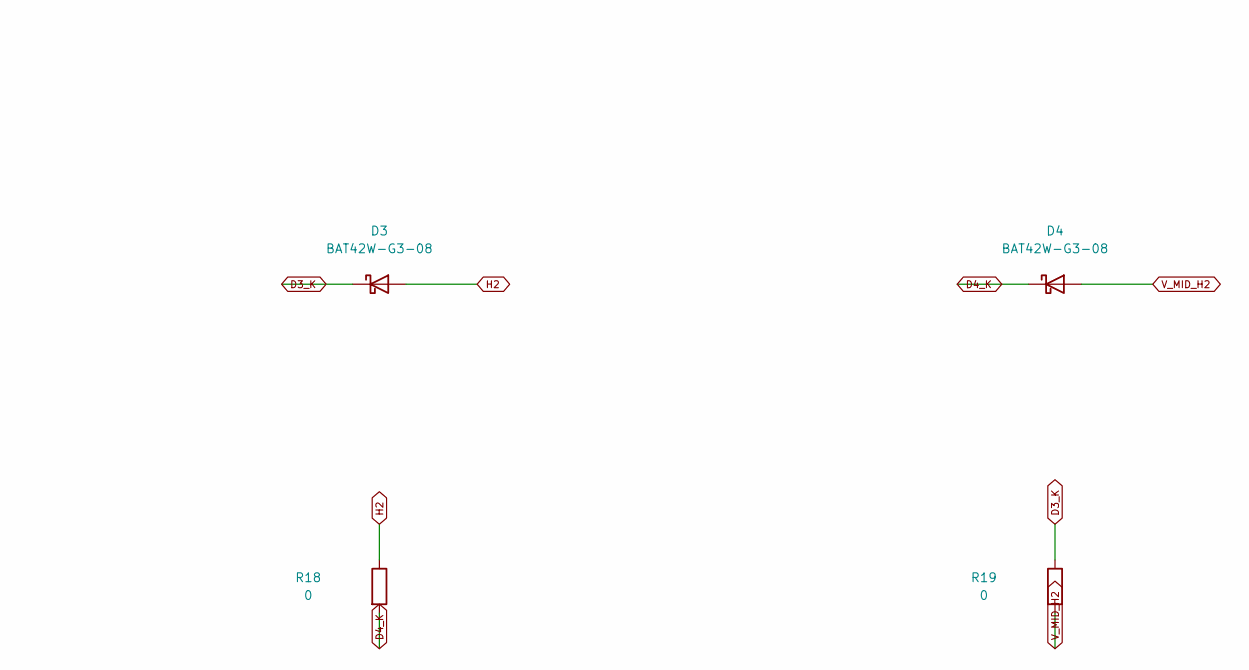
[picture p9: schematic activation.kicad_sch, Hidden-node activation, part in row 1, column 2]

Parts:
D1, D2, D3, D4: BAT42W-G3-08; D_SOD-123; MPN BAT42W-G3-08
R16, R17, R18, R19: 0; R_0805_2012Metric; Tolerance Jumper; MPN CRCW08050000Z0EA

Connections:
D1_K: D1.1 (K), R16.1
D2_K: D2.1 (K), R17.2
D3_K: D3.1 (K), R19.1
D4_K: D4.1 (K), R18.2
H1: D1.2 (A), R17.1; also elsewhere on the board
H2: D3.2 (A), R18.1; also elsewhere on the board
V_MID_H1: D2.2 (A), R16.2; also elsewhere on the board
V_MID_H2: D4.2 (A), R19.2; also elsewhere on the board

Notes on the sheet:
Hidden-node activation — see docs/ee-review.md for equations, limits and sources.

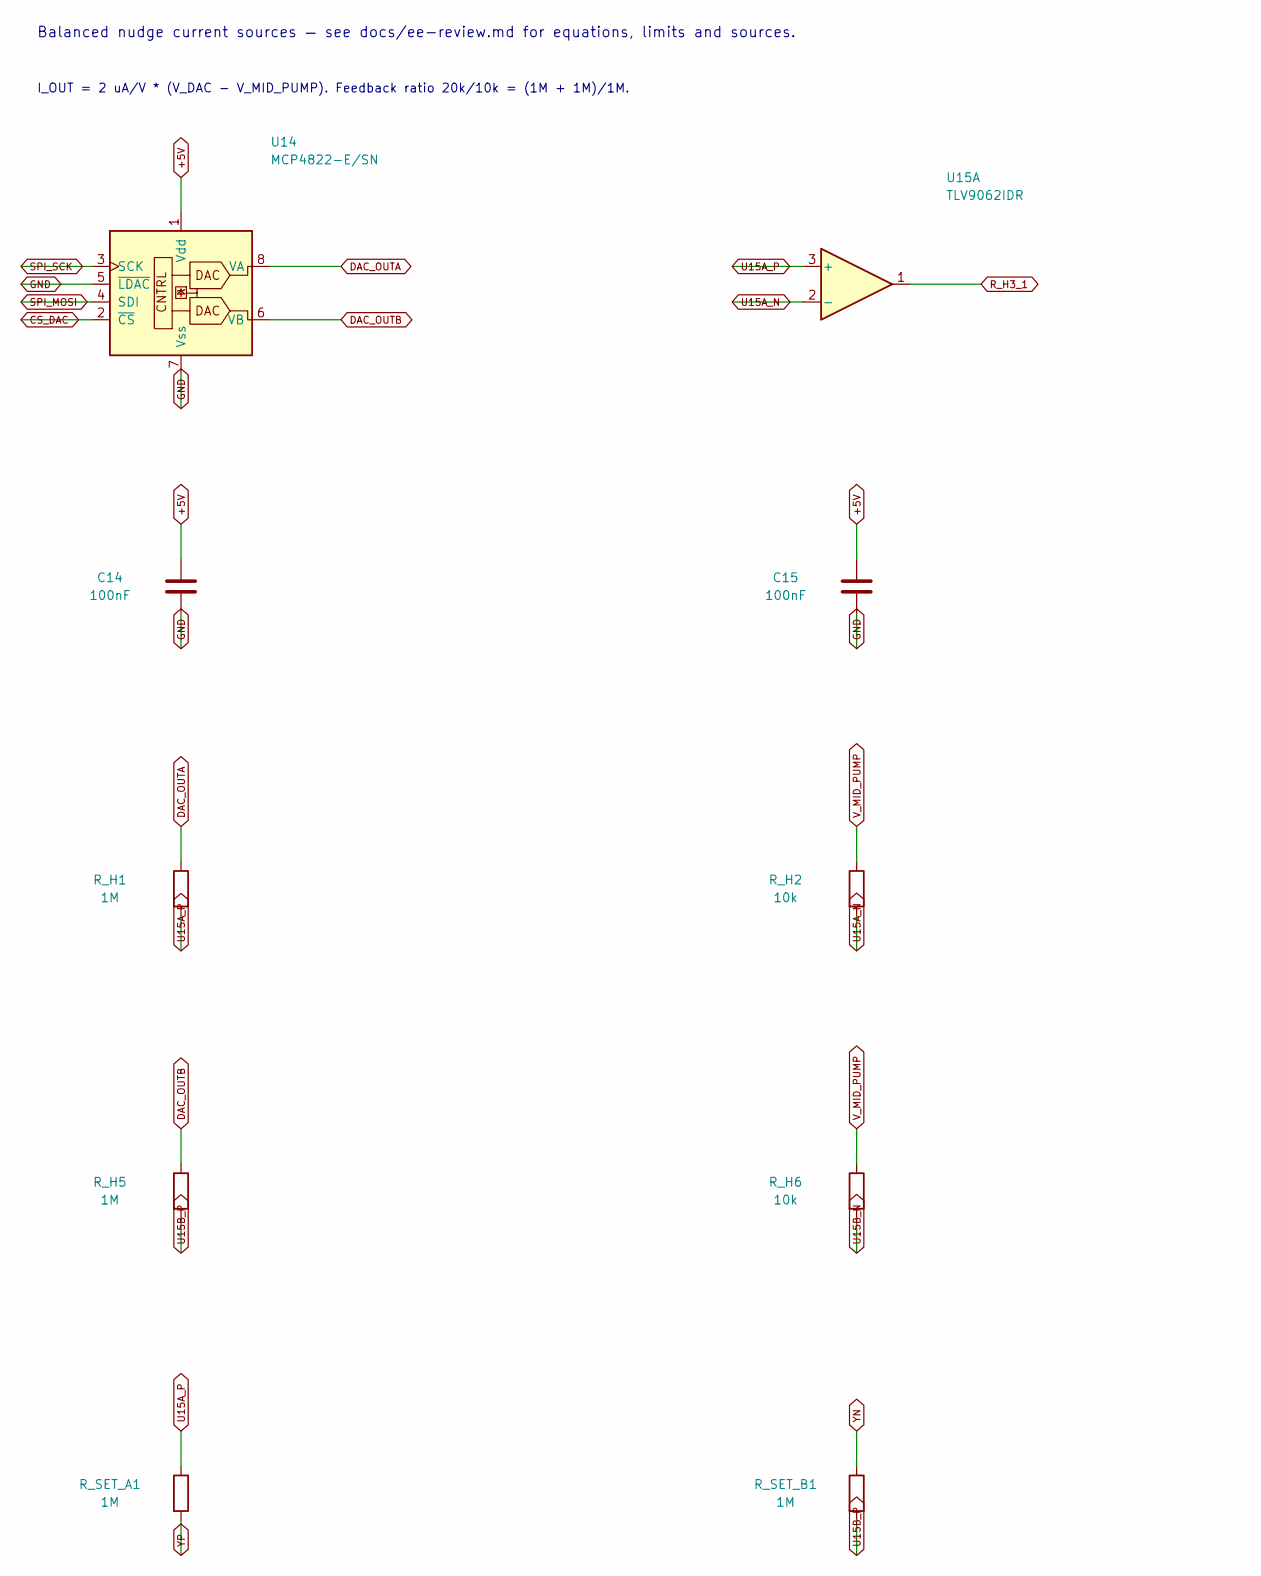
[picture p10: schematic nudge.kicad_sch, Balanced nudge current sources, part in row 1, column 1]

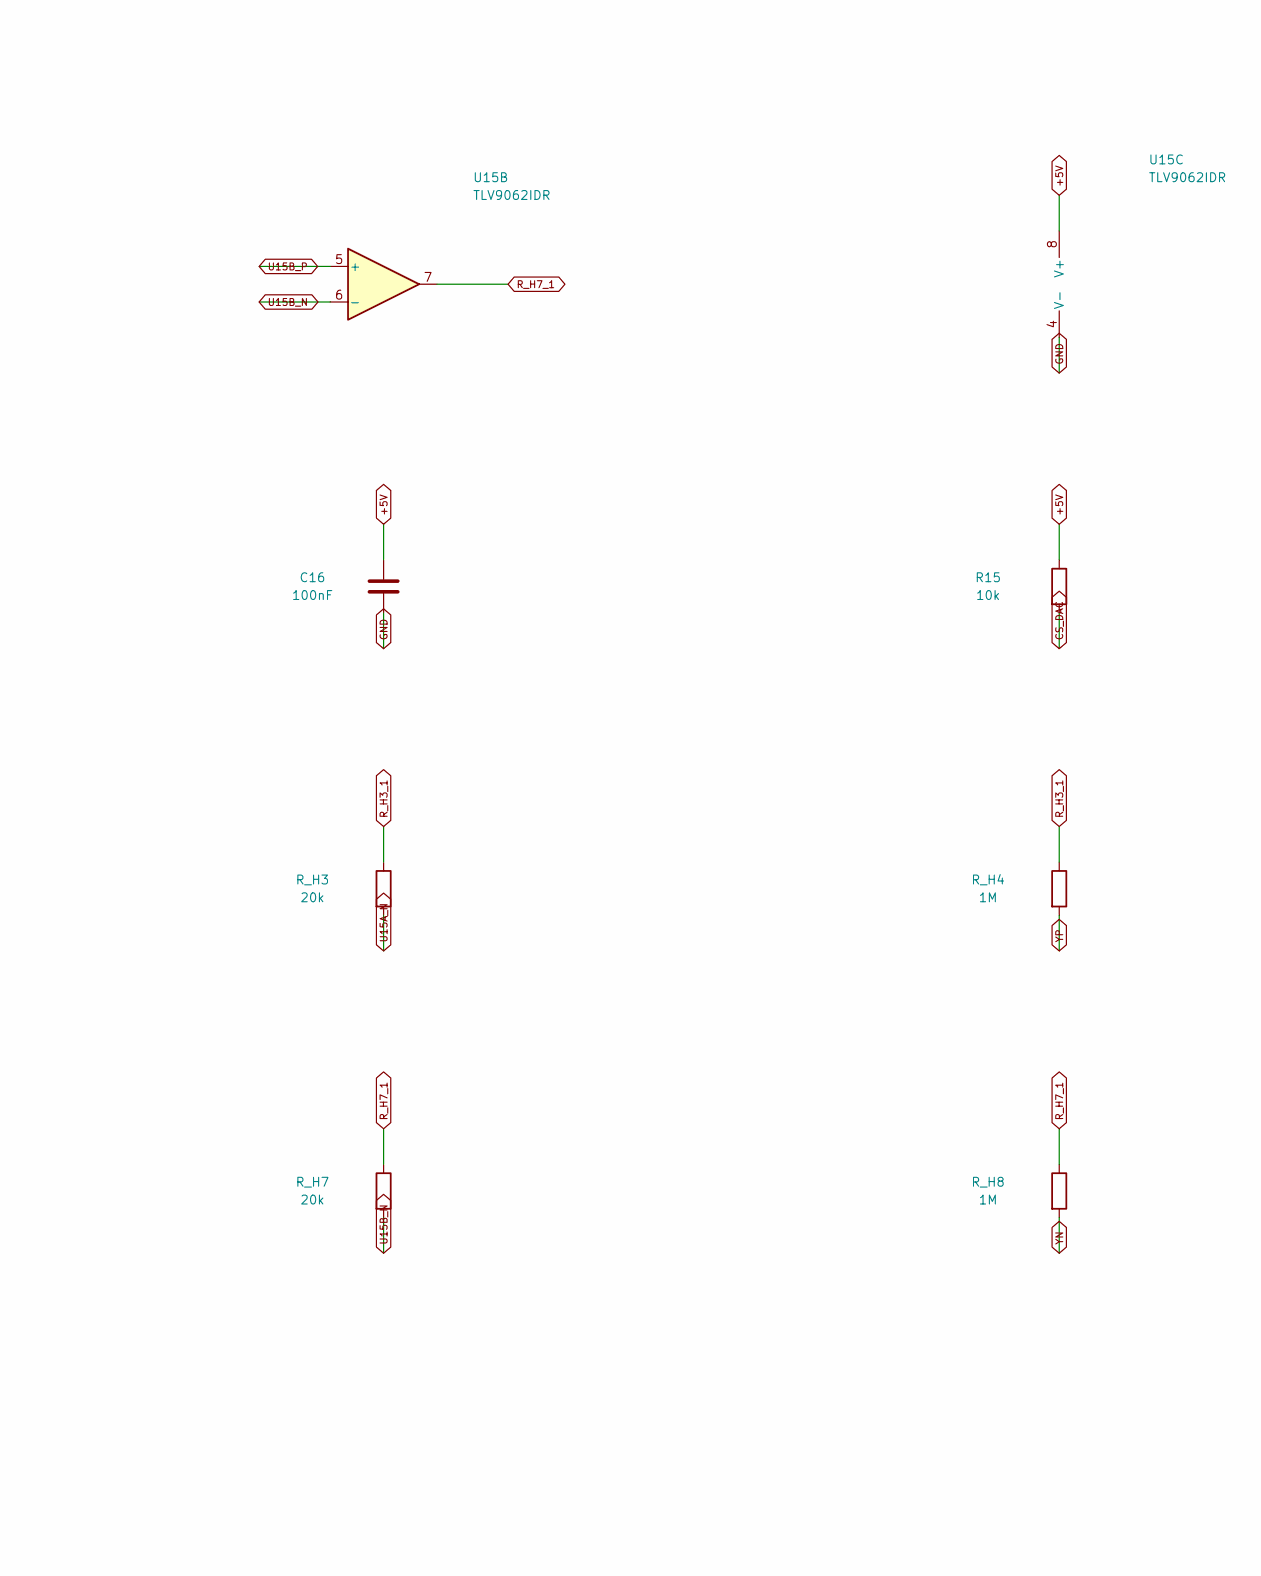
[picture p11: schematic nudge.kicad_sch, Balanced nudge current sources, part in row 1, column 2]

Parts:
C14, C15, C16: 100nF; C_0805_2012Metric; MPN C0805C104K5RACTU
R15: 10k; R_0805_2012Metric; Tolerance 1%; MPN CRCW080510K0FKEA
R_H1, R_H4, R_H5, R_H8: 1M; R_0805_2012Metric; Tolerance 0.1%; MPN TNPW08051M00BEEA
R_H2, R_H6: 10k; R_0805_2012Metric; Tolerance 0.1%; MPN TNPW080510K0BEEA
R_H3, R_H7: 20k; R_0805_2012Metric; Tolerance 0.1%; MPN TNPW080520K0BEEA
R_SET_A1: 1M; R_0805_2012Metric; Tolerance 0.1%; MPN TNPW08051M00BEEA
R_SET_B1: 1M; R_0805_2012Metric; Tolerance 0.1%; MPN TNPW08051M00BEEA
U14: MCP4822-E/SN; SOIC-8_3.9x4.9mm_P1.27mm; MPN MCP4822-E/SN
U15: TLV9062IDR; SOIC-8_3.9x4.9mm_P1.27mm; MPN TLV9062IDR

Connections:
+5V: C14.1, C15.1, C16.1, R15.1, U14.1 (Vdd), U15.8 (V+); also elsewhere on the board
CS_DAC: R15.2, U14.2 (~CS); also elsewhere on the board
DAC_OUTA: R_H1.1, U14.8 (VA); also elsewhere on the board
DAC_OUTB: R_H5.1, U14.6 (VB); also elsewhere on the board
GND: C14.2, C15.2, C16.2, U14.5 (~LDAC), U14.7 (Vss), U15.4 (V-); also elsewhere on the board
R_H3_1: R_H3.1, R_H4.1, U15.1
R_H7_1: R_H7.1, R_H8.1, U15.7
SPI_MOSI: U14.4 (SDI); also elsewhere on the board
SPI_SCK: U14.3 (SCK); also elsewhere on the board
U15A_N: R_H2.2, R_H3.2, U15.2 (-)
U15A_P: R_H1.2, R_SET_A1.1, U15.3 (+)
U15B_N: R_H6.2, R_H7.2, U15.6 (-)
U15B_P: R_H5.2, R_SET_B1.2, U15.5 (+)
V_MID_PUMP: R_H2.1, R_H6.1; also elsewhere on the board
YN: R_H8.2, R_SET_B1.1; also elsewhere on the board
YP: R_H4.2, R_SET_A1.2; also elsewhere on the board

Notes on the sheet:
Balanced nudge current sources — see docs/ee-review.md for equations, limits and sources.
I_OUT = 2 uA/V * (V_DAC - V_MID_PUMP). Feedback ratio 20k/10k = (1M + 1M)/1M.

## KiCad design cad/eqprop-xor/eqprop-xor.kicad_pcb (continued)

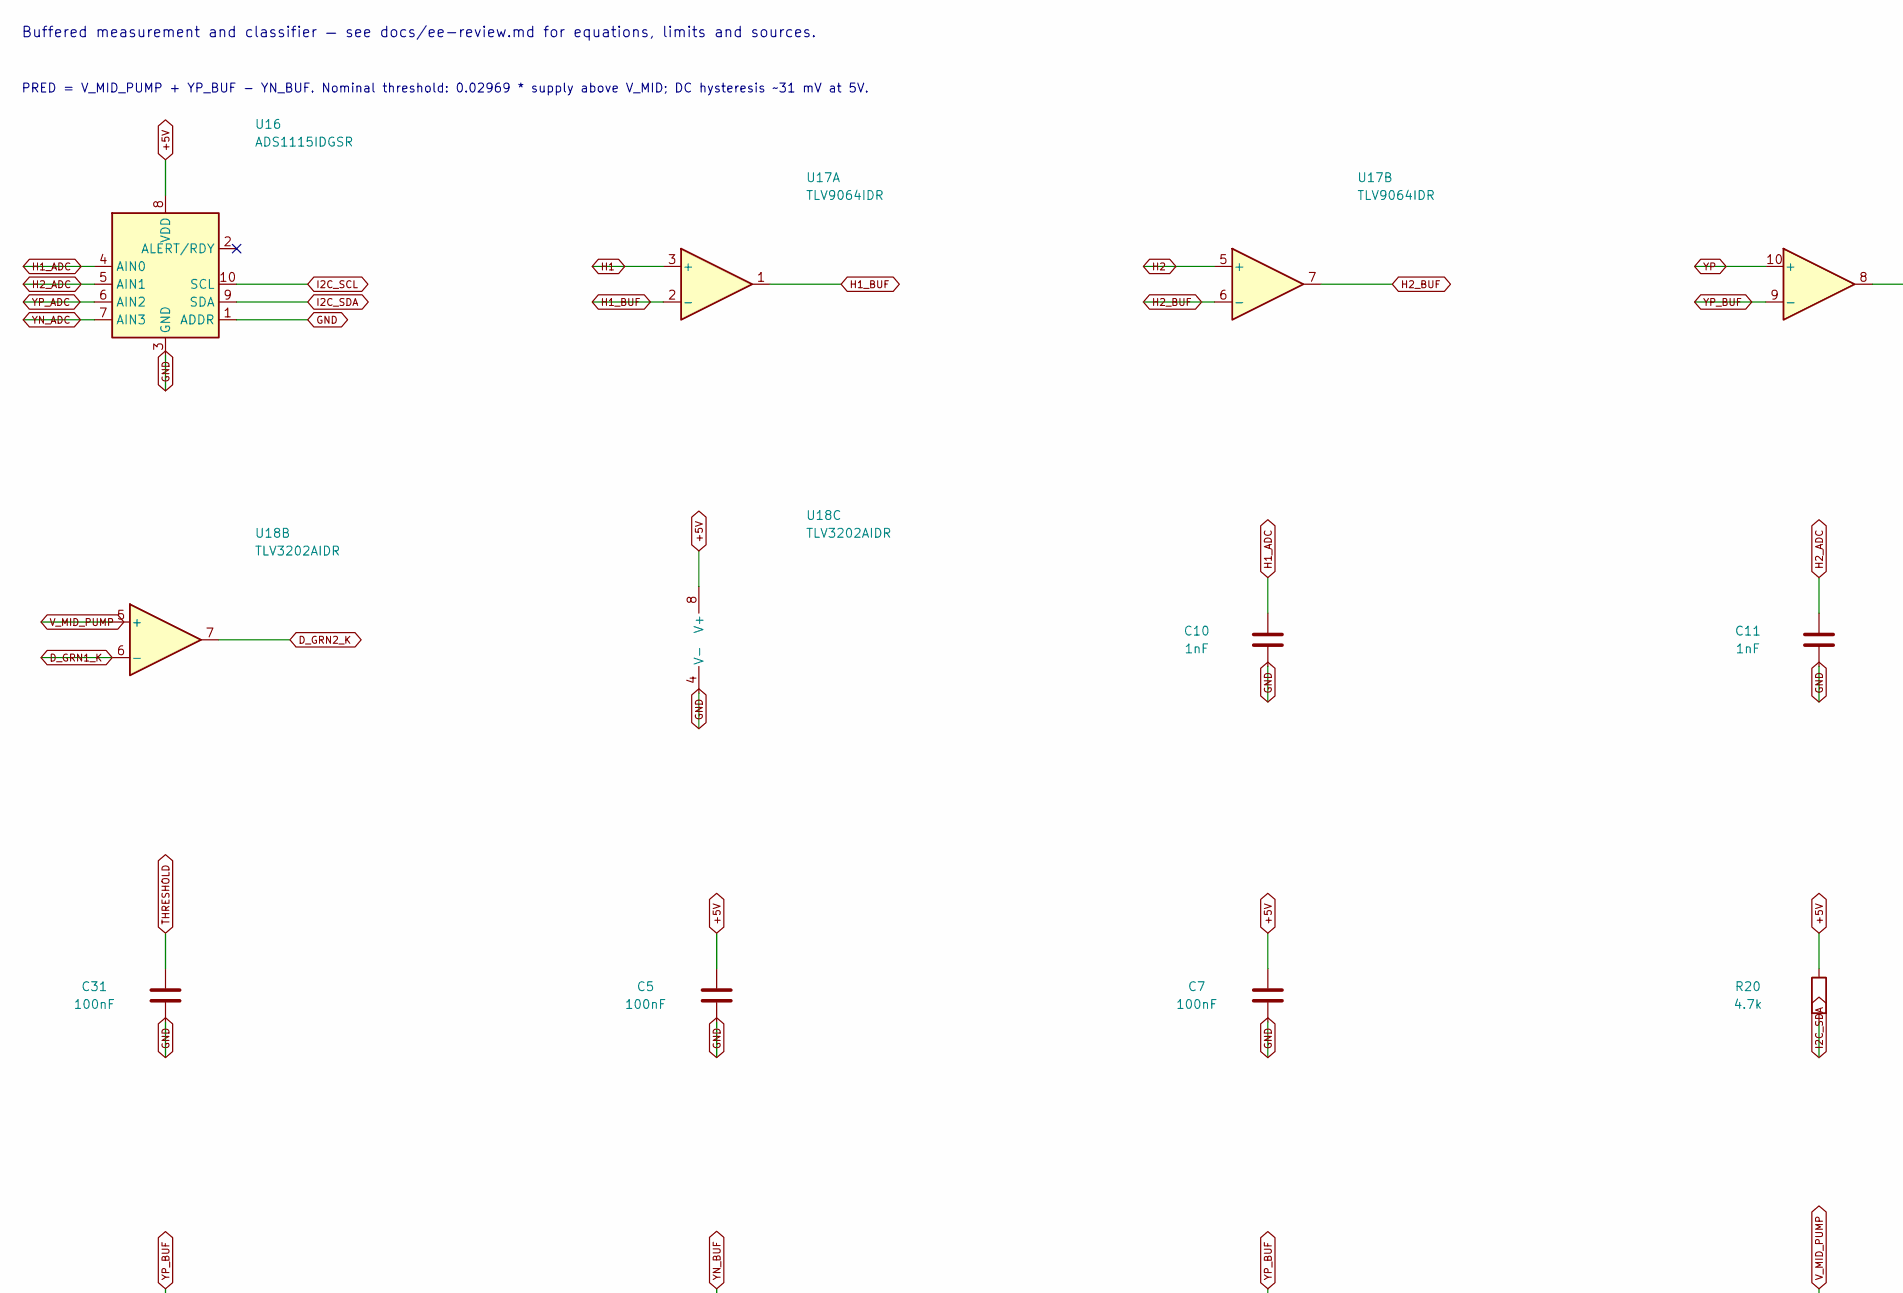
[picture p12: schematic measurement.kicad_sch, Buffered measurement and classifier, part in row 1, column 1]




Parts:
C5, C7, C17, C31: 100nF; C_0805_2012Metric; MPN C0805C104K5RACTU
C10, C11, C27, C28: 1nF; C_0805_2012Metric; MPN C0805C102J5GACTU
R20, R21: 4.7k; R_0805_2012Metric; Tolerance 1%; MPN CRCW08054K70FKEA
R_ADC1, R_ADC2, R_ADC3, R_ADC4: 100; R_0805_2012Metric; Tolerance 1%; MPN CRCW0805100RFKEA
R_D1, R_D2, R_D3, R_D4: 100k; R_0805_2012Metric; Tolerance 0.1%; MPN TNPW0805100KBEEA
R_HYS1: 10k; R_0805_2012Metric; Tolerance 1%; MPN CRCW080510K0FKEA
R_HYS2: 2M; R_0805_2012Metric; Tolerance 1%; MPN CRCW08052M00FKEA
R_LED_G1: 2.2k; R_0805_2012Metric; Tolerance 1%; MPN CRCW08052K20FKEA
R_LED_R1: 2.2k; R_0805_2012Metric; Tolerance 1%; MPN CRCW08052K20FKEA
R_TH1: 4.99k; R_0805_2012Metric; Tolerance 0.1%; MPN TNPW08054K99BEEA
R_TH2: 5.62k; R_0805_2012Metric; Tolerance 0.1%; MPN TNPW08055K62BEEA
TP1, TP2, TP3, TP4, TP5, TP6, TP7, TP8, TP9, TP10, TP11, TP12, TP13, TP14, TP15, TP16: TestPoint; TestPoint_Pad_1.0x1.0mm; MPN PCB copper feature (no component)
U16: ADS1115IDGSR; TSSOP-10_3x3mm_P0.5mm; MPN ADS1115IDGSR
U17: TLV9064IDR; SOIC-14_3.9x8.7mm_P1.27mm; MPN TLV9064IDR
U18: TLV3202AIDR; SOIC-8_3.9x4.9mm_P1.27mm; MPN TLV3202AIDR

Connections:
+5V: C5.1, C7.1, C17.1, R20.1, R21.1, R_LED_G1.2, R_LED_R1.2, R_TH1.1, TP13.1, U16.8 (VDD), U17.4 (V+), U18.8 (V+); also elsewhere on the board
DAC_OUTA: TP8.1; also elsewhere on the board
DAC_OUTB: TP9.1; also elsewhere on the board
D_GRN1_A: R_LED_G1.1; also elsewhere on the board
D_GRN1_K: R_HYS2.1, U18.1, U18.6 (-); also elsewhere on the board
D_GRN2_A: R_LED_R1.1; also elsewhere on the board
D_GRN2_K: U18.7; also elsewhere on the board
GND: C5.2, C7.2, C10.2, C11.2, C17.2, C27.2, C28.2, C31.2, R_TH2.2, TP12.1, TP14.1, U16.1 (ADDR), U16.3 (GND), U17.11 (V-), U18.4 (V-); also elsewhere on the board
H1: TP6.1, U17.3 (+); also elsewhere on the board
H1_ADC: C10.1, R_ADC1.2, U16.4 (AIN0)
H1_BUF: R_ADC1.1, U17.1, U17.2 (-)
H2: TP7.1, U17.5 (+); also elsewhere on the board
H2_ADC: C11.1, R_ADC2.2, U16.5 (AIN1)
H2_BUF: R_ADC2.1, U17.6 (-), U17.7
I2C_SCL: R21.2, U16.10 (SCL); also elsewhere on the board
I2C_SDA: R20.2, U16.9 (SDA); also elsewhere on the board
PRED: R_D4.1, TP15.1, U18.2 (-); also elsewhere on the board
PRED_MINUS: R_D3.2, R_D4.2; also elsewhere on the board
PRED_PLUS: R_D1.2, R_D2.2; also elsewhere on the board
THRESHOLD: C31.1, R_HYS1.1, R_TH1.2, R_TH2.1, TP16.1
THRESHOLD_HYS: R_HYS1.2, R_HYS2.2, U18.3 (+)
V_HIGH: TP2.1; also elsewhere on the board
V_LOW: TP1.1; also elsewhere on the board
V_MID_H1: TP3.1; also elsewhere on the board
V_MID_H2: TP4.1; also elsewhere on the board
V_MID_PUMP: R_D2.1, TP5.1, U18.5 (+); also elsewhere on the board
YN: TP11.1, U17.12 (+); also elsewhere on the board
YN_ADC: C28.1, R_ADC4.2, U16.7 (AIN3)
YN_BUF: R_ADC4.1, R_D3.1, U17.13 (-), U17.14
YP: TP10.1, U17.10 (+); also elsewhere on the board
YP_ADC: C27.1, R_ADC3.2, U16.6 (AIN2)
YP_BUF: R_ADC3.1, R_D1.1, U17.8, U17.9 (-)

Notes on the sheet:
Buffered measurement and classifier — see docs/ee-review.md for equations, limits and sources.
PRED = V_MID_PUMP + YP_BUF - YN_BUF. Nominal threshold: 0.02969 * supply above V_MID; DC hysteresis ~31 mV at 5V.

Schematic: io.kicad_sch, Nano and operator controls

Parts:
D_GRN1, D_GRN2: Green low-current 3mm; LED_D3.0mm; MPN WP710A10LZGCK
D_PWR1: Green low-current 3mm; LED_D3.0mm; MPN WP710A10LZGCK
R_BUTTON1: 2.2k; R_0805_2012Metric; MPN CRCW08052K20FKEA
R_SW1, R_SW2: 10k; R_0805_2012Metric; Tolerance 1%; MPN CRCW080510K0FKEA
SW1, SW2: SW_SPDT; SW_E-Switch_EG1271_SPDT; MPN EG1271A
SW3: LEARN / STOP; SW_SPST_B3U-1000P; MPN B3U-1000P
U3: Arduino_Nano_v3.x; Arduino_Nano; MPN A000005

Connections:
+5V: R_BUTTON1.1, SW1.1 (A), SW2.1 (A), U3.27 (+5V); also elsewhere on the board
CS_DAC: U3.12 (D9); also elsewhere on the board
CS_POT1: U3.7 (D4); also elsewhere on the board
CS_POT2: U3.8 (D5); also elsewhere on the board
CS_POT3: U3.9 (D6); also elsewhere on the board
CS_POT4: U3.10 (D7); also elsewhere on the board
CS_POT5: U3.11 (D8); also elsewhere on the board
CS_POT6: U3.13 (D10); also elsewhere on the board
CS_POT7: U3.21 (A2); also elsewhere on the board
CS_POT8: U3.22 (A3); also elsewhere on the board
D_GRN1_A: D_GRN1.2 (A); also elsewhere on the board
D_GRN1_K: D_GRN1.1 (K); also elsewhere on the board
D_GRN2_A: D_GRN2.2 (A); also elsewhere on the board
D_GRN2_K: D_GRN2.1 (K); also elsewhere on the board
D_PWR1_A: D_PWR1.2 (A); also elsewhere on the board
GND: D_PWR1.1 (K), SW1.3 (C), SW2.3 (C), SW3.2, U3.4 (GND), U3.29 (GND); also elsewhere on the board
I2C_SCL: U3.24 (A5); also elsewhere on the board
I2C_SDA: U3.23 (A4); also elsewhere on the board
LEARN_BUTTON: R_BUTTON1.2, SW3.1, U3.25 (A6)
MUX_A: R_SW1.1, U3.5 (D2); also elsewhere on the board
MUX_B: R_SW2.1, U3.6 (D3); also elsewhere on the board
SPI_MISO: U3.15 (D12); also elsewhere on the board
SPI_MOSI: U3.14 (D11); also elsewhere on the board
SPI_SCK: U3.16 (D13); also elsewhere on the board
SW1_B: R_SW1.2, SW1.2 (B)
SW2_B: R_SW2.2, SW2.2 (B)
X1: U3.19 (A0); also elsewhere on the board
X2: U3.20 (A1); also elsewhere on the board

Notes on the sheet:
Nano and operator controls — see docs/ee-review.md for equations, limits and sources.
SW3: active-low A6 analog input; external pull-up required. Firmware: analogRead(A6), AVcc reference; debounce and act only at phase boundaries. B3U-1000P is NOT washable; assemble after any wet cleaning.


Board: 2 copper layers, 106.0 x 88.0 mm, 151 parts (0 on the bottom side), 91 nets.

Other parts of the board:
MH1, MH2, MH3, MH4: M3; MountingHole_3.2mm_M3

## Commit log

2026-02-15 Initial commit: XOR proof-of-concept via equilibrium propagation
    Generic KCL solver, EqProp training loop with symmetric nudge,
    ngspice cross-validation, and 24-test pytest suite. XOR converges
    in ~1800 epochs with 16 digital pot weights and BAT42 diode
    activation functions. Hardware design spec included.
2026-02-16 Add weight quantization for hardware readiness validation
    Add tap quantization utilities to WeightParams (resistance_to_tap,
    tap_to_resistance, quantize_weights) and refactor xor.py to use them
    instead of inline formula. Add 4 quantization tests verifying XOR
    survives round-trip through MCP4251 tap positions and ±2 tap shifts.
2026-02-16 Add KiCad schematic guide and update hardware design docs
    Step-by-step KiCad schematic entry guide (8 sections covering power,
    Arduino, muxes, weights, diodes, nudge, and measurement). Updated
    design.md and CLAUDE.md to reflect MCP6004 replacing LM324 for
    V_LOW/V_HIGH buffers and MCP4251 pin requirements.
2026-02-16 Add full-circuit SPICE simulation with hardware non-idealities
    Model the complete analog signal path before PCB fabrication:
    voltage dividers + op-amp buffers (MCP6004, LM324), CD4053B mux
    on-resistance, and Howland current pumps (MCP6002). Three-way
    cross-validation (Python/ideal SPICE/full-circuit) confirms all
    4 XOR patterns classify correctly with trained weights.
2026-02-16 Update BOM component values across simulator, SPICE, and docs
    Align all component values with actual DigiKey-sourced BOM parts:
    - Series protection resistor: 1.2kΩ → 1.21kΩ (E96 metal film)
    - V_LOW/V_HIGH dividers: 8kΩ/2kΩ → 33kΩ/8.2kΩ (E24 standard)
    - Derived values: R_min 1590→1600Ω, R_max 101200→101210Ω
    - V_LOW≈0.995V, V_HIGH≈4.005V (from divider, sum exactly 5.0V)
    - Replace 0Ω jumper diode pads with solder bridges (no BOM part)
    - Add DigiKey BOM CSV with verified in-stock MPNs
    - Update power budget for lower divider quiescent current
    - All 40 tests pass, XOR converges at ~1770 epochs
    [bom_digikey.csv]
2026-02-17 Add KiCad project with Section 1 schematic (power + voltage references)
    USB-C power input, three voltage dividers (V_MID/V_LOW/V_HIGH),
    MCP6004 and LM324 op-amp buffers, bulk caps, and test points.
    [eqprop-xor.kicad_pcb, eqprop-xor.kicad_sch]
2026-02-18 Add Arduino Nano section with CS pull-ups and text annotations
    Section 2: Arduino Nano pin assignments, 9x 10kΩ CS pull-up resistors,
    bulk decoupling caps placed near analog/digital clusters, and text
    annotations for readability.
    [eqprop-xor.kicad_sch]
2026-02-18 Add input muxes and inference toggle switches
    Section 3: 2x CD4053B analog muxes (direct + complementary inputs),
    decoupling caps, SPDT toggle switches with 10kΩ isolation resistors
    for inference mode.
    [eqprop-xor.kicad_sch]
2026-02-18 Add 8x MCP4251 weight resistors with series protection
    Section 4: 8x MCP4251-104 digital potentiometers (16 weight channels),
    16x 1.21kΩ series protection resistors, and 8x 100nF decoupling caps.
    [eqprop-xor.kicad_sch]
2026-02-18 Add section labels and title block annotations
    [eqprop-xor.kicad_sch]
2026-02-18 Added schematic snapshot image
2026-02-21 Complete schematic: sections 5-7 and documentation update
    Sections 5-7: BAT42 activation diodes with solder bridge pads,
    MCP4822 DAC + MCP6002 Howland current pumps, ADS1115 ADC with
    I2C pull-ups, and LED comparators on U1D/U2D.
    Updated KiCad overview doc to be a concise reference with KiCad 9
    notes (symbol naming, CD4053B pin mapping, footprint assignment).
    [eqprop-xor.kicad_sch]
2026-02-27 Started PCB design
    [bom_digikey.csv, eqprop-xor.kicad_pcb, eqprop-xor.kicad_sch]
2026-09-11 Complete B.1 EqProp PCB and document fabrication and firmware handoff
    [activation.kicad_sch, bom-pcbway.csv, bom_digikey.csv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]
